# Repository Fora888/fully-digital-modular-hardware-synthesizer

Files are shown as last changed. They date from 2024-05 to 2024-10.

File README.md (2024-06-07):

# Fully digital modular synthesizer
A fully digital modular synthesizer specification

## Specification

### Audio data format
The audio data is transmitted and processed at 44.1kHz sample rate and 16 Bits of resolution

### Data transmission
Data transmission utilizes UART in combination with a simple protocol.
UART is configured at a baud rate of 2,000,000 with 8 data bits, 1 stop bit, no flow control and regular polarity. Signal levels are defined as 0V for low and 3.3V for high. However, all inputs and outputs should withstand voltages from +12V to -12V to prevent accidental damage when interfaced with analog equipment.
Due to UART's limitation of transmitting only 8 bits at a time and each audio sample requiring 16 bits, each sample is transmitted as three sequential packets. Each packet consists of 6 data bits followed by 2 order bits. Therefore a full UART frame looks like the following:
|1|6|2|1|
|-|-|-|-|
|Start bit|Data bits|Order bits|Stop bit|

The least significant 8 bits of a sample are sent first with order bits '00', followed by the middle 8 bits with order bits '10', and finally the most significant 4 bits with order bits '01'. The last two data bits of the last packet with order bits '01', as well as the order bit combination '11', remain unused for now but could be utilized for future extensions.

### Power
Modules are connected to +5V and ground via a 6 pin, 2 row, 2.54mm (0.1 inch) spacing header connector. These use the following pinout:

| | | |
| --- | --- | --- |
| 5v  | 5v  | GND |
| GND | GND | GND |

This asymmetric pattern ensures, that in case the header is plugged in incorrectly, the power supply is short-circuited  and the module doesn't get damaged. Therefore it is advisable for power supplys to feature some sort of fusing mechanism.
Since noisy power doesn't impact the sound quality of digital audio, switching power supplys are sufficient for voltage conversion

### Mechanical
Since UART necessitates only one cable for transmission, akin to mono audio, the mechanical specifications of virtually any existing analog modular synthesizer can be used. The examples are based on eurorack the eurorack specification with 128mm height and 3.5mm TS (mono) phone connectors.

## Comparison to analog

### Advantages
**Less noise** - Digital transmission ensures that the audio signal is received exactly as it was sent, without introducing noise during transmission. Furthermore many analog modules use analog-to-digital and digital-to-analog conversion, which introduce noise into the signal

**Reduced complexity** - Digital signals don't require clean power or buffering in order to deliver good audio. Merely two diodes and one or two resistors, which are always in the exact same configuration, are required per input or output. In addition all I/O is full 16 bit and the audio is inherently DC coupled.

**Lower Price** - Microprocessors are cheap and require relatively few and simple auxiliary components when compared to analog electronics. The reduced complexity of digital signal processing also leads to lower development costs.

### Disadvantages
**Latency** - Digital signal processing always comes with latency. In case of the examples, where audio is processed in blocks of 128 samples, this latency comes in at ~3 ms per module. Fast processors can however reduce the block size, reducing the latency to half of that or even less.

**Module selection** - The digital protocol described is still in its early stages of development and therefore there are no manufacturers for it yet. So the only way to use it is to build your own modules

## Implementations and examples
An implementation for the teensy audio library as well as several example modules can be found in the [Teensy](https://github.com/Fora888/fully-digital-modular-hardware-synthesizer/tree/main/Teensy) folder.

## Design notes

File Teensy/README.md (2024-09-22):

# Teensy audio library extension
## TeensyDigitalModularExtension
This folder is a arduino library, which contains an implementation of the protocol as input and output blocks for the teensy audio library, as well as arduino sketches and auxiliary blocks for several example modules listed below. The library can easily be imported with the zip file and the following guide: https://docs.arduino.cc/software/ide-v1/tutorials/installing-libraries/.

## PCB
This folder contains PCBs as well as panel designs for the example modules. All PCBs use 2.54mm spacing between components, which means you can also build these modules on perfboard and connect the components with wire, instead of ordering PCBs

### VCA
<p float="left">
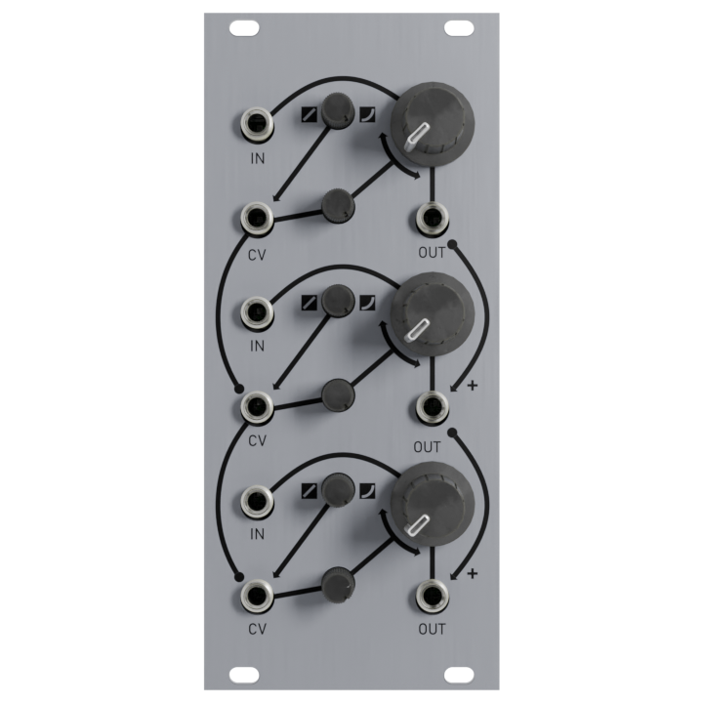
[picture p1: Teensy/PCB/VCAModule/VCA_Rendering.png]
  
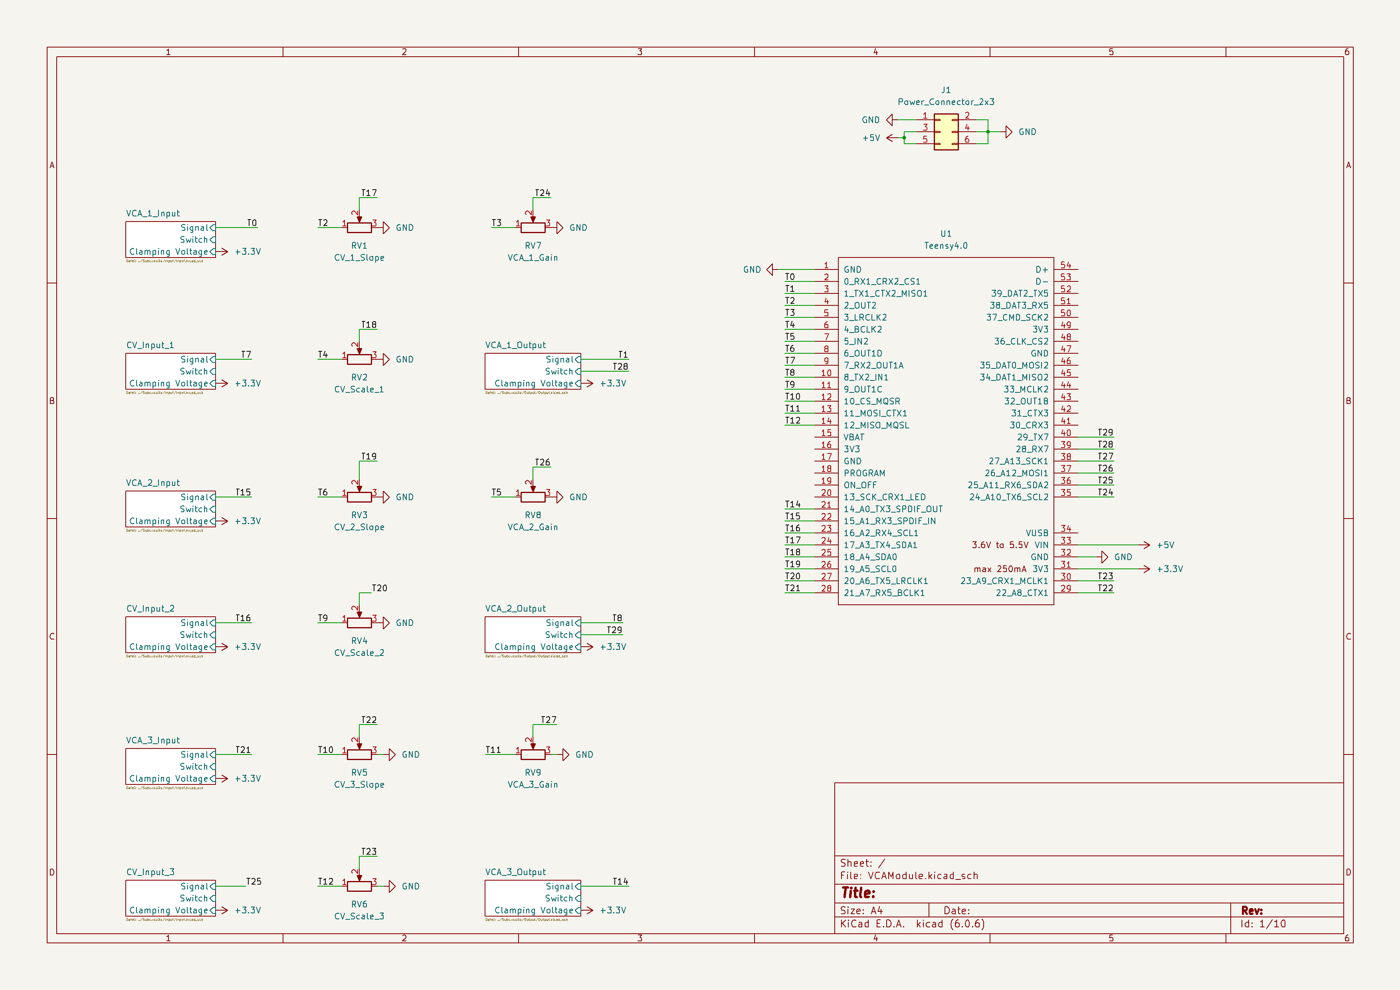
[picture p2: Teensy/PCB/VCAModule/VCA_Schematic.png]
  
</p>

### ADSR envelope generator
<p float="left">
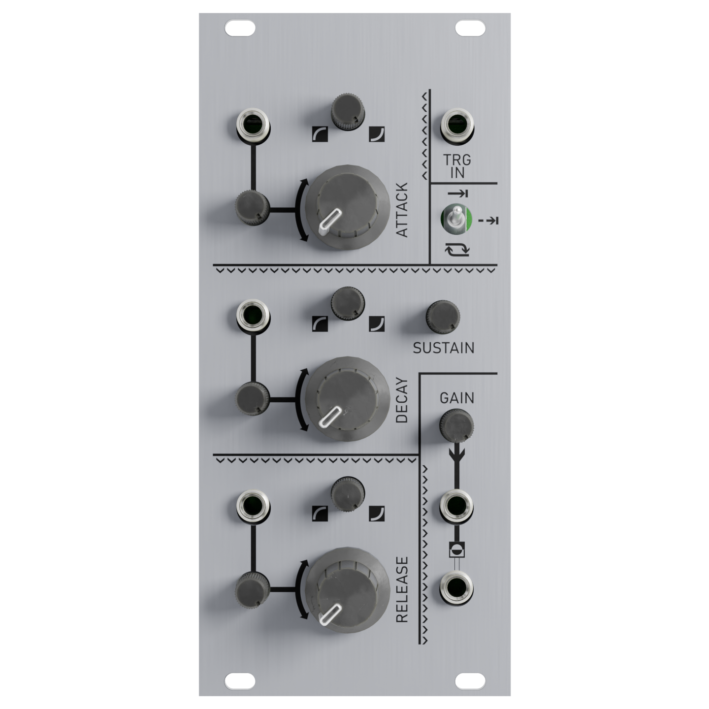
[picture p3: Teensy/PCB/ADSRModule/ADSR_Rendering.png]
  
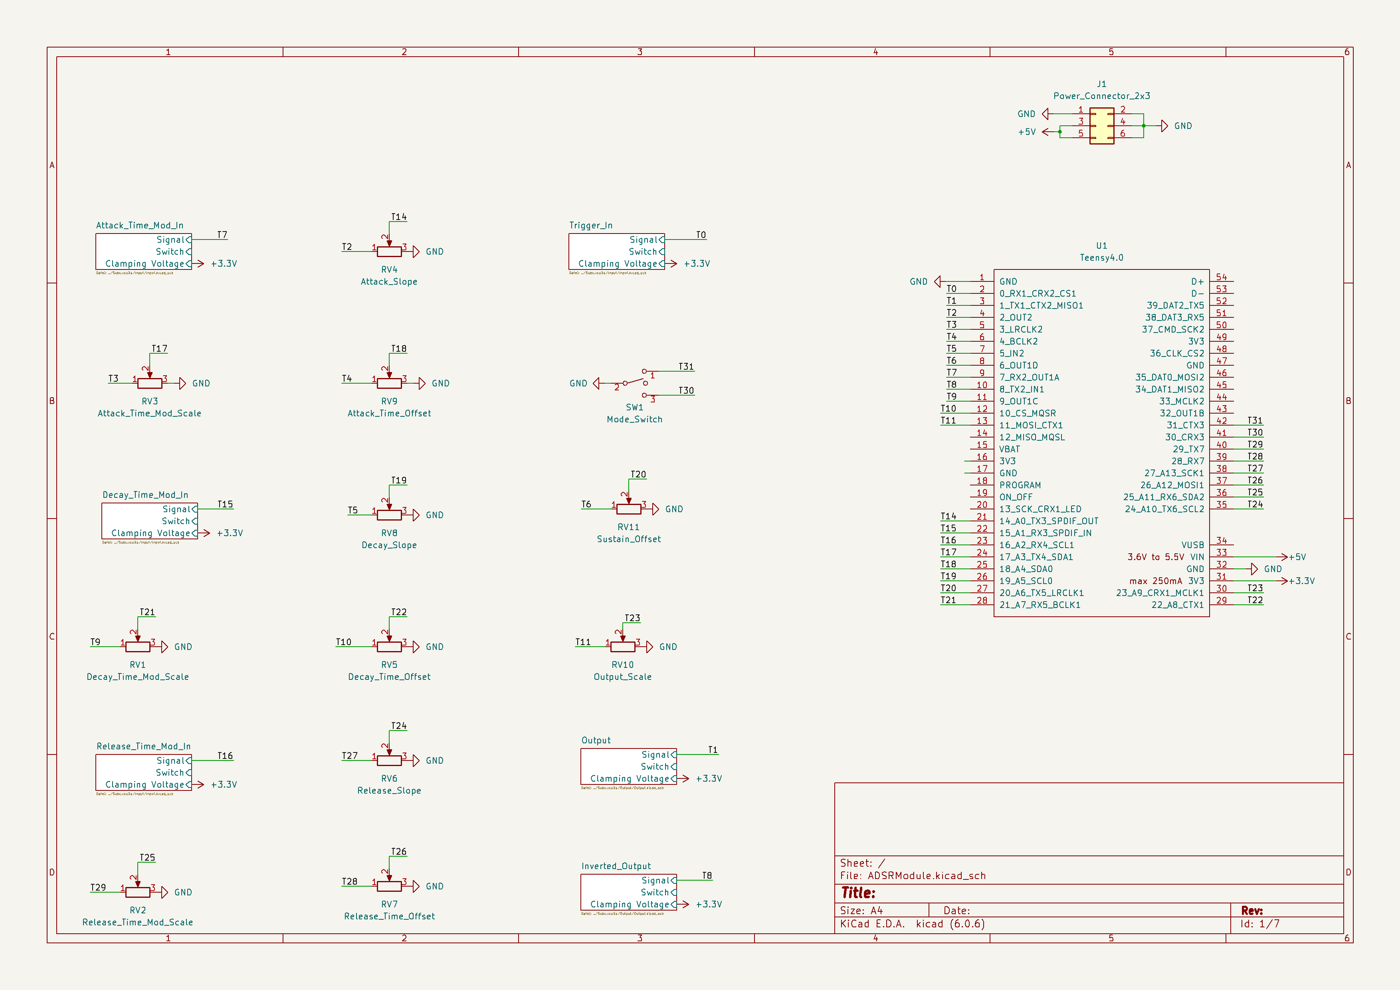
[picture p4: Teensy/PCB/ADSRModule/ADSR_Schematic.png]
  
</p>

### Wavetable oscillator
<p float="left">
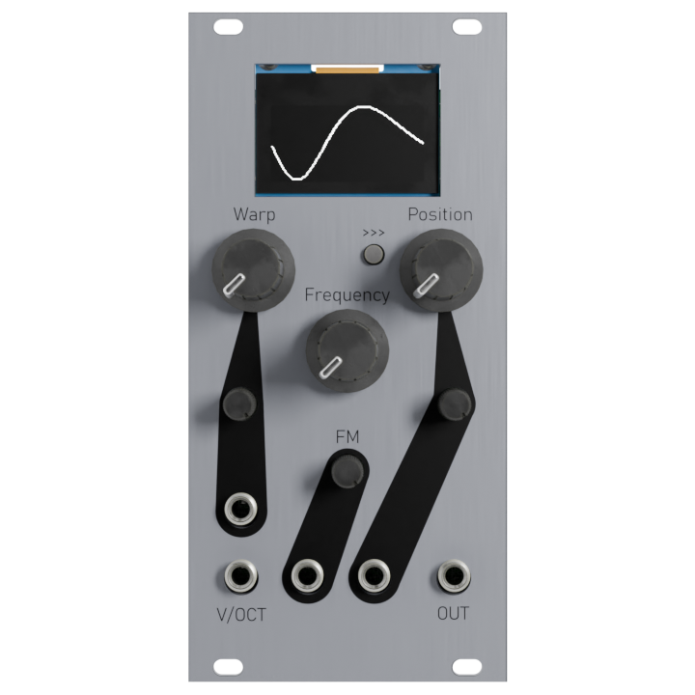
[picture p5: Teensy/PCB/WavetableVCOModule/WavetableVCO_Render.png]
  
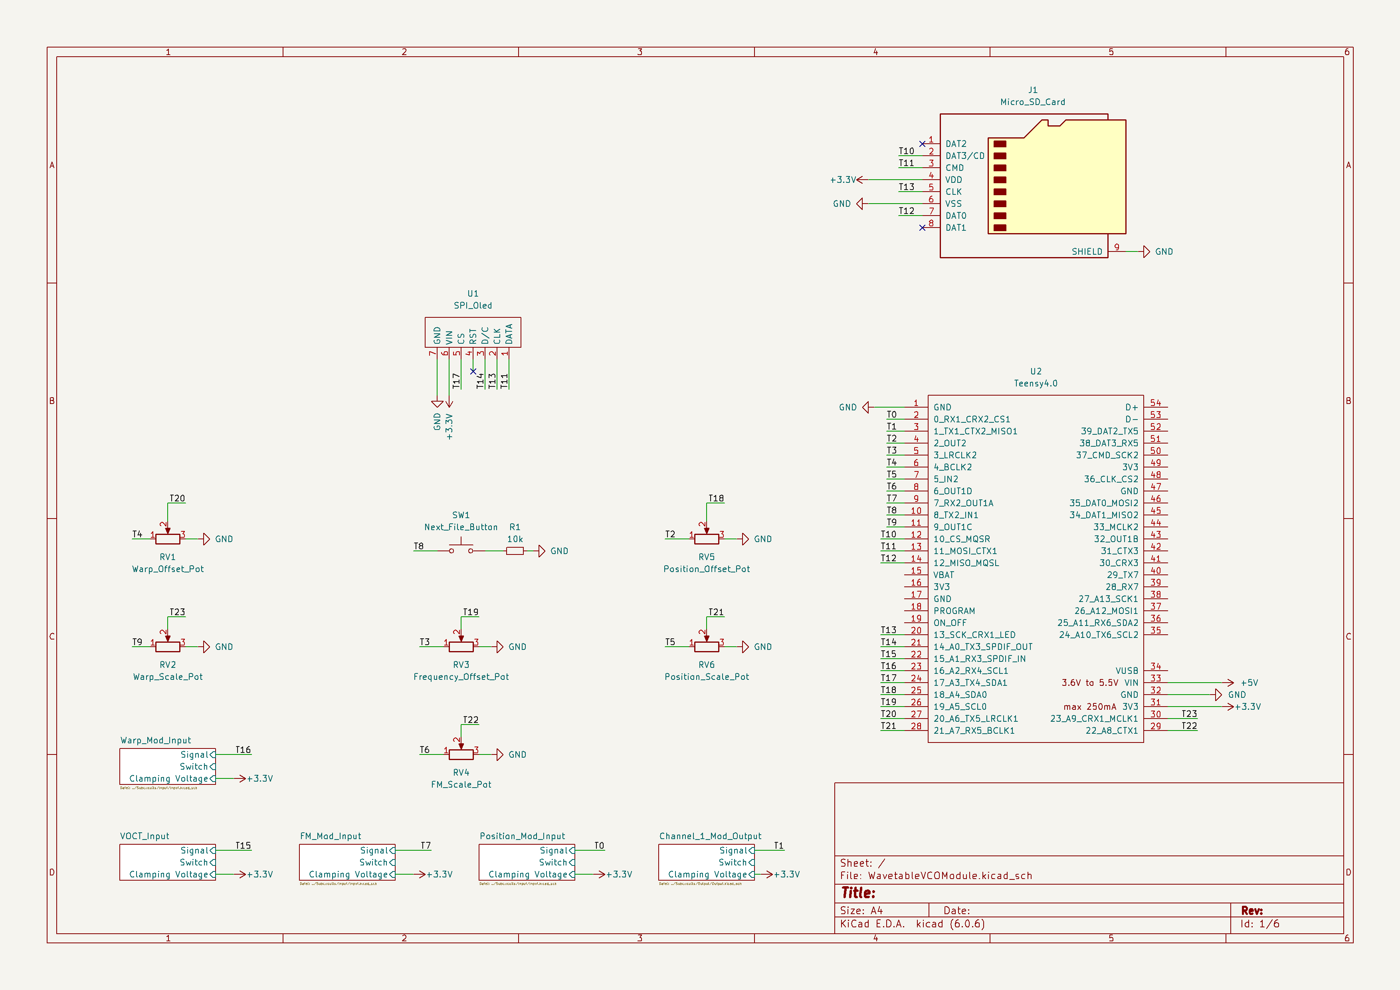
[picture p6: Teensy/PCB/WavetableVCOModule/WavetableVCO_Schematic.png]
  
</p>

### USB I/O
<p float="left">
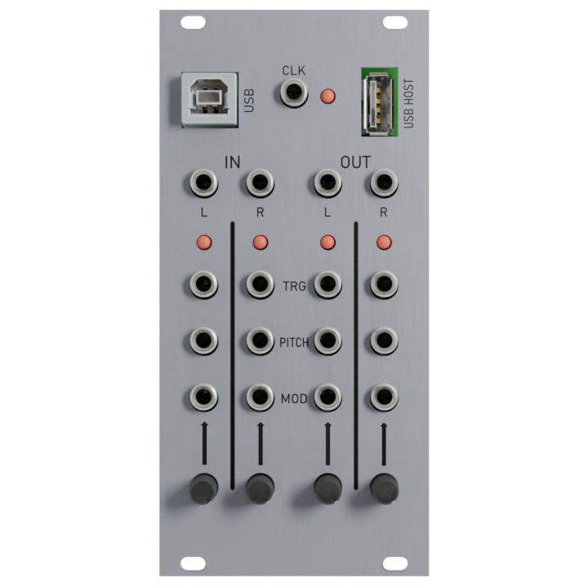
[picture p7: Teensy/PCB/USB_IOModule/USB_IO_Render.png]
  
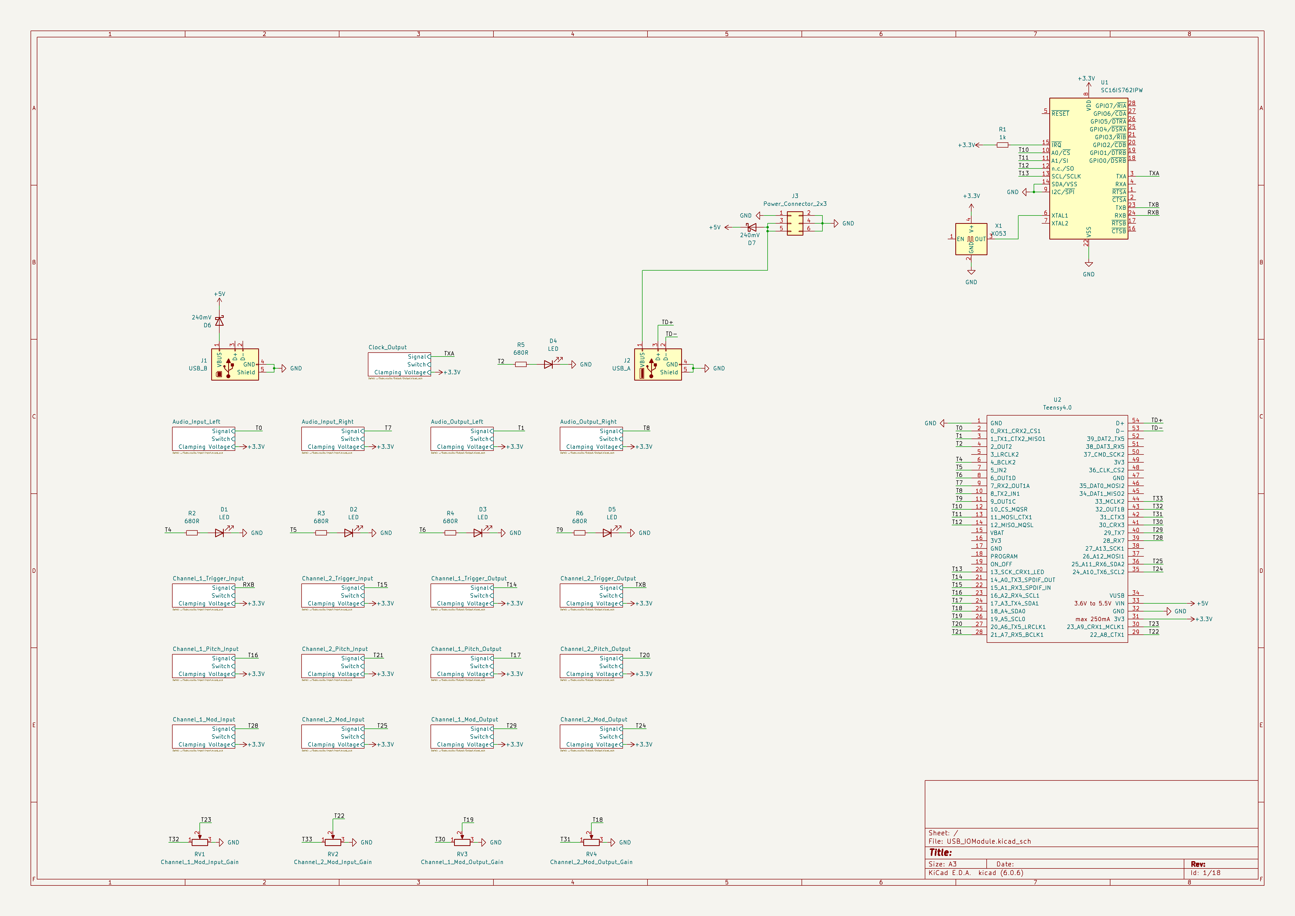
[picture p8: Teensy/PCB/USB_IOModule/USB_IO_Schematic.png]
  
</p>

### Analog I/O

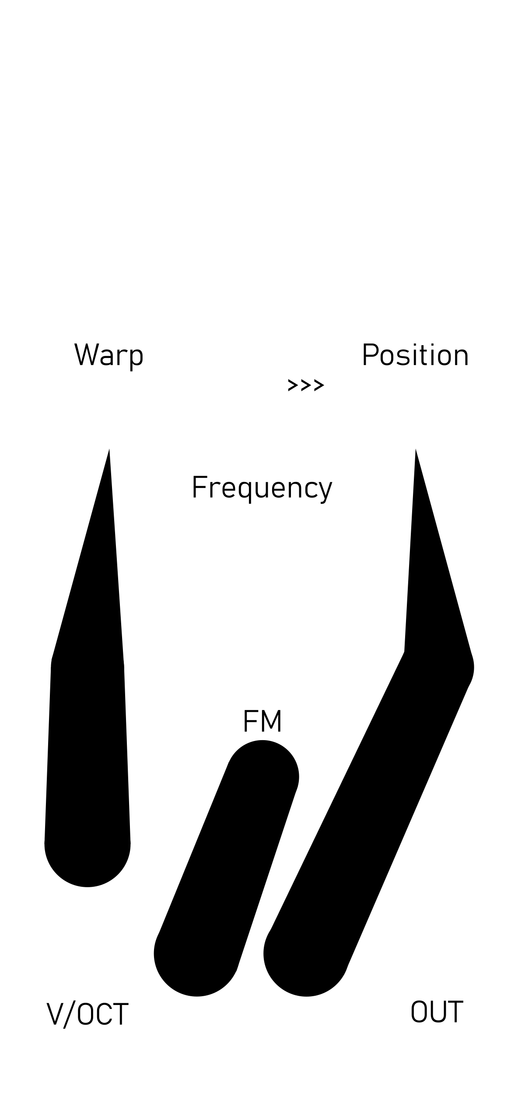
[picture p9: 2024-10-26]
Teensy/PCB/WavetableVCOModule/WavetableVCO_Artwork.png

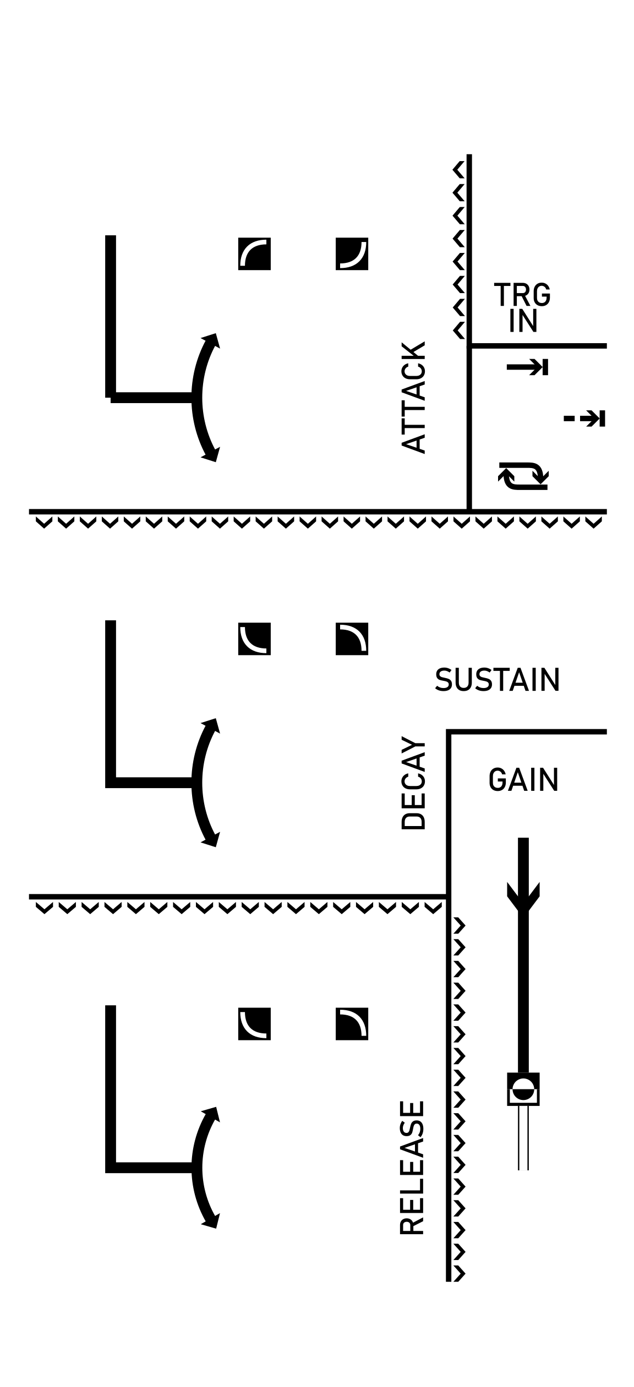
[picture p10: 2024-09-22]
Teensy/PCB/ADSRModule/ADSR_Artwork.png

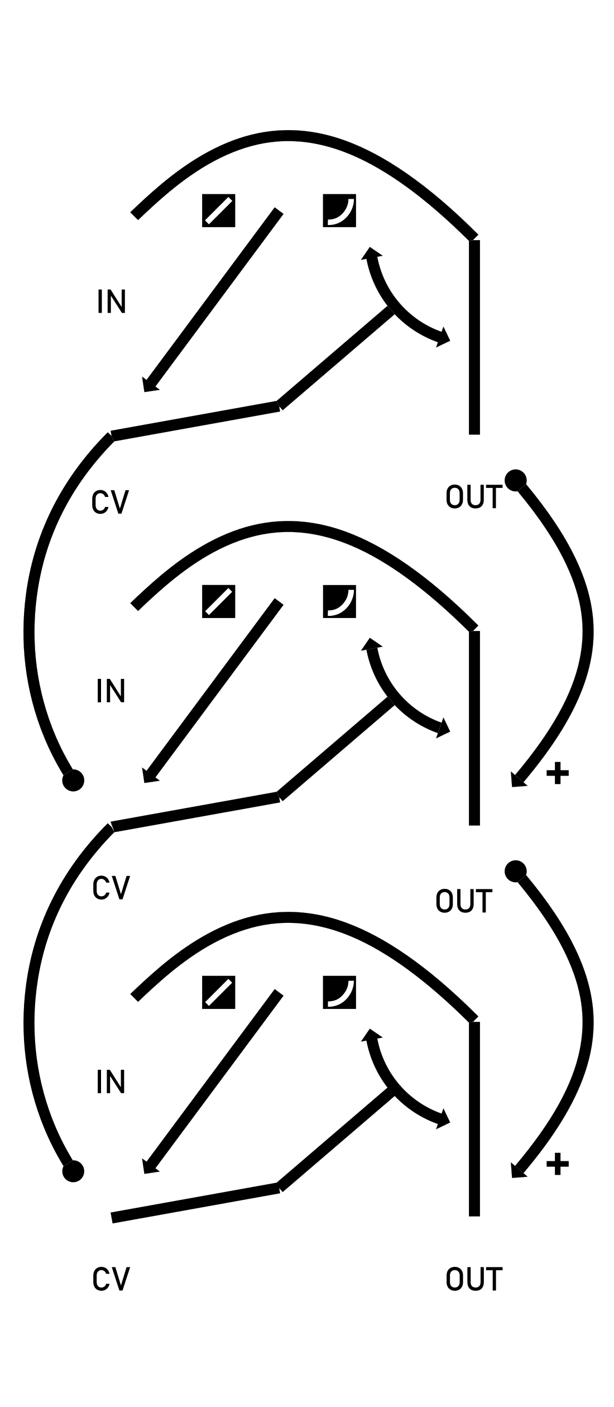
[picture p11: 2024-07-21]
Teensy/PCB/VCAModule/VCA_Artwork.png

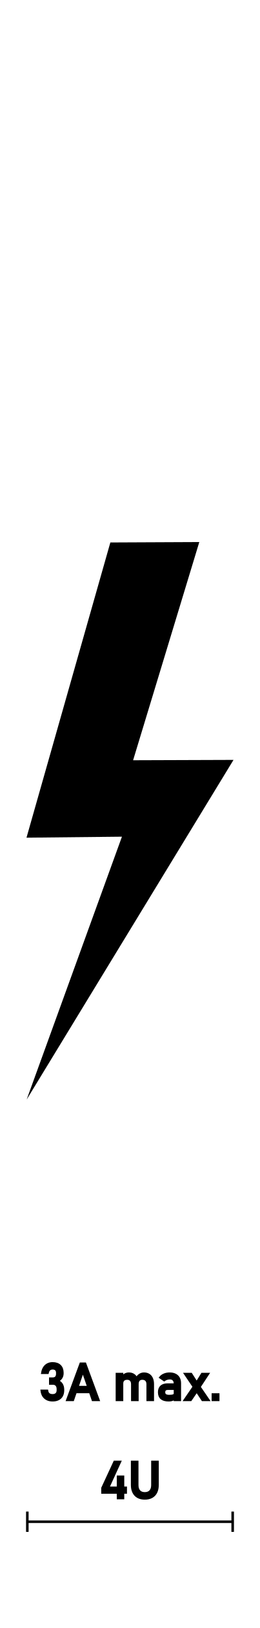
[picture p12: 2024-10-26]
Power Supply/USB-C_3A_PSU/USB-C_3A_PSU_Artwork.png

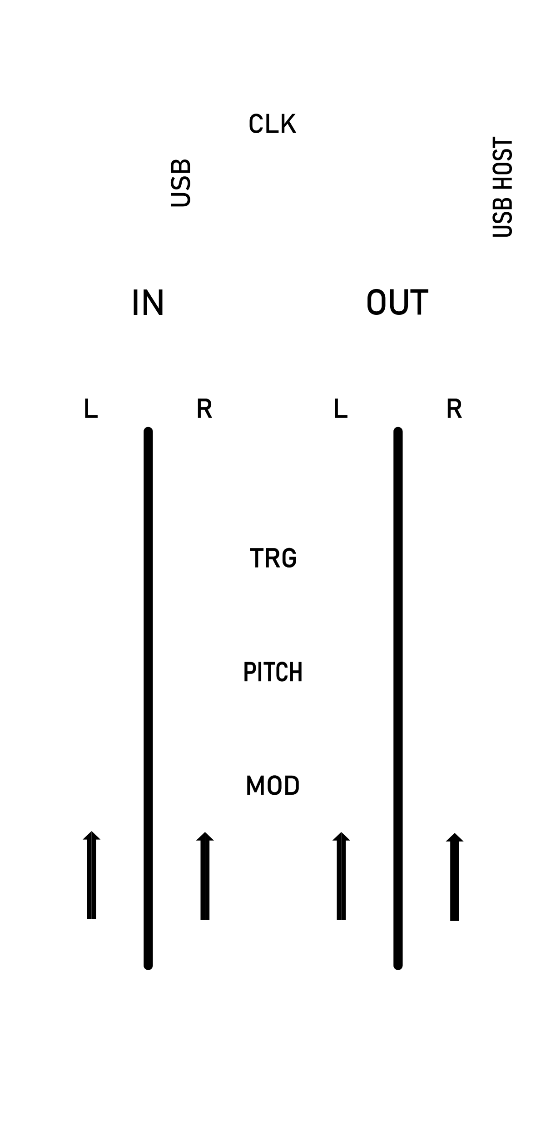
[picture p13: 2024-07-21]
Teensy/PCB/USB_IOModule/USB_IO_Artwork.png

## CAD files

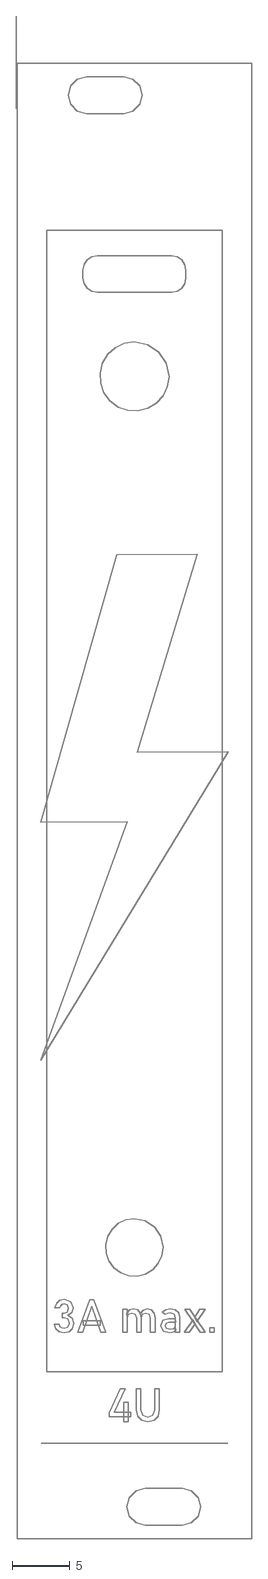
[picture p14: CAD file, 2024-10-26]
Power Supply/USB-C_3A_PSU/USB-C_3A_PSU_Cut.dxf
20.4 x 132.1

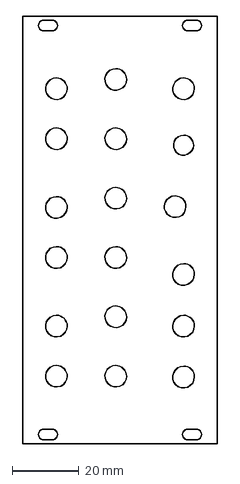
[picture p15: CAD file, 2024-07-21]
Teensy/PCB/ADSRModule/ADSR_Cut.dxf
58.4 x 128.0 mm

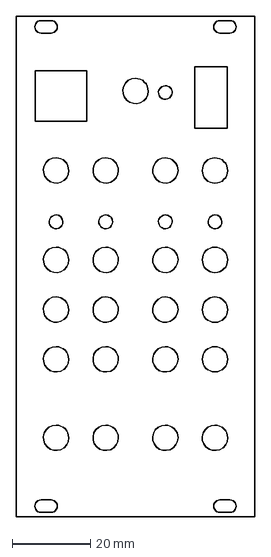
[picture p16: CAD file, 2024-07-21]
Teensy/PCB/USB_IOModule/USB_IO_Cut.dxf
61.0 x 128.0 mm

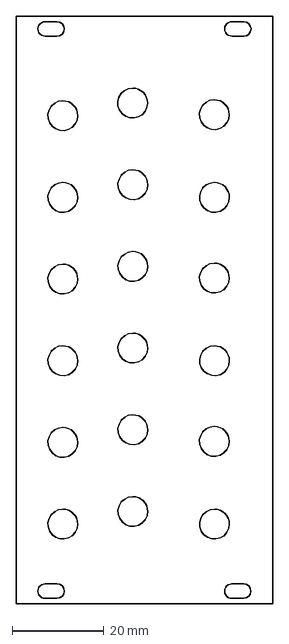
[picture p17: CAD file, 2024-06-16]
Teensy/PCB/VCAModule/VCA_Cut.dxf
55.8 x 127.9 mm

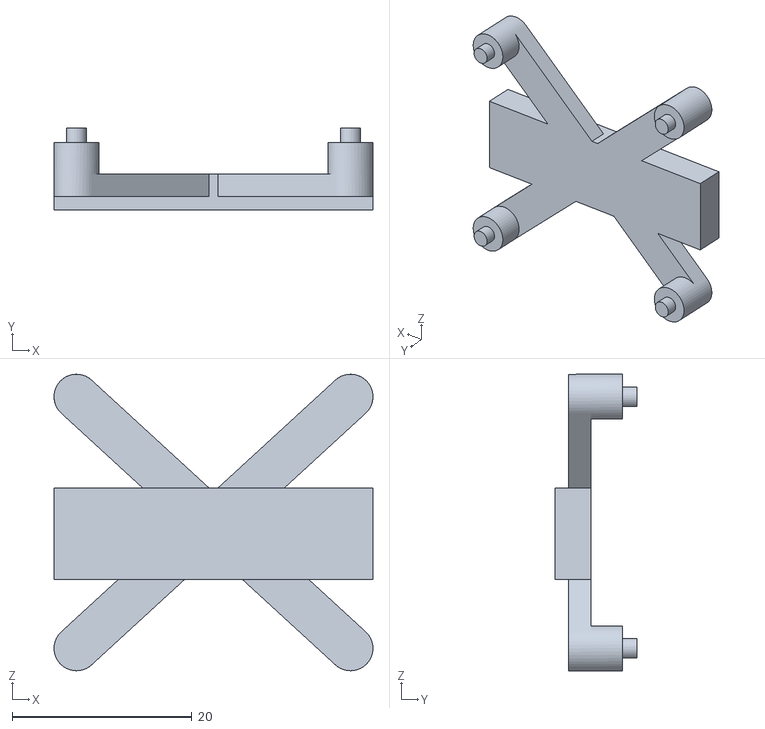
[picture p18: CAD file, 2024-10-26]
Teensy/PCB/WavetableVCOModule/WavetableVCO_OLEDBracket.stl
35.5 x 9.10 x 33.0

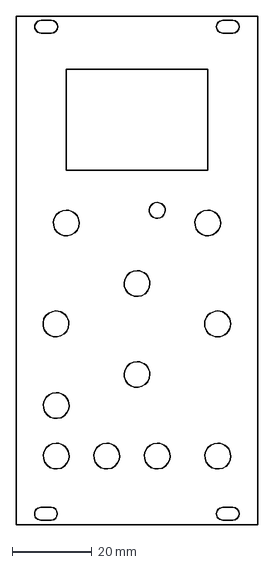
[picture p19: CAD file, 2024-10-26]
Teensy/PCB/WavetableVCOModule/WavetableVCO_Cut.dxf
60.8 x 127.9 mm

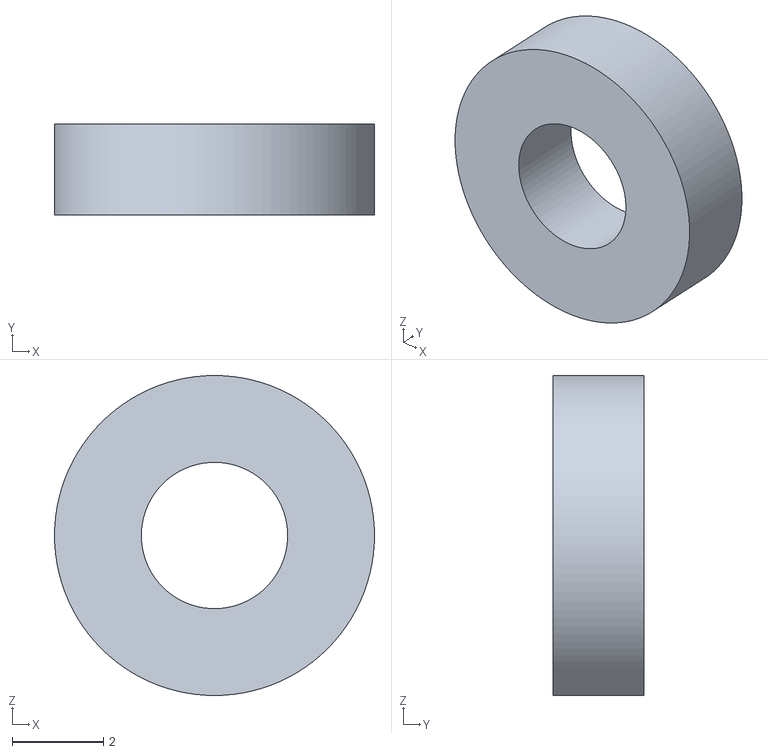
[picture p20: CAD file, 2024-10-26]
Teensy/PCB/WavetableVCOModule/WavetableVCO_ScrewSpacer.stl
7.00 x 2.00 x 7.00

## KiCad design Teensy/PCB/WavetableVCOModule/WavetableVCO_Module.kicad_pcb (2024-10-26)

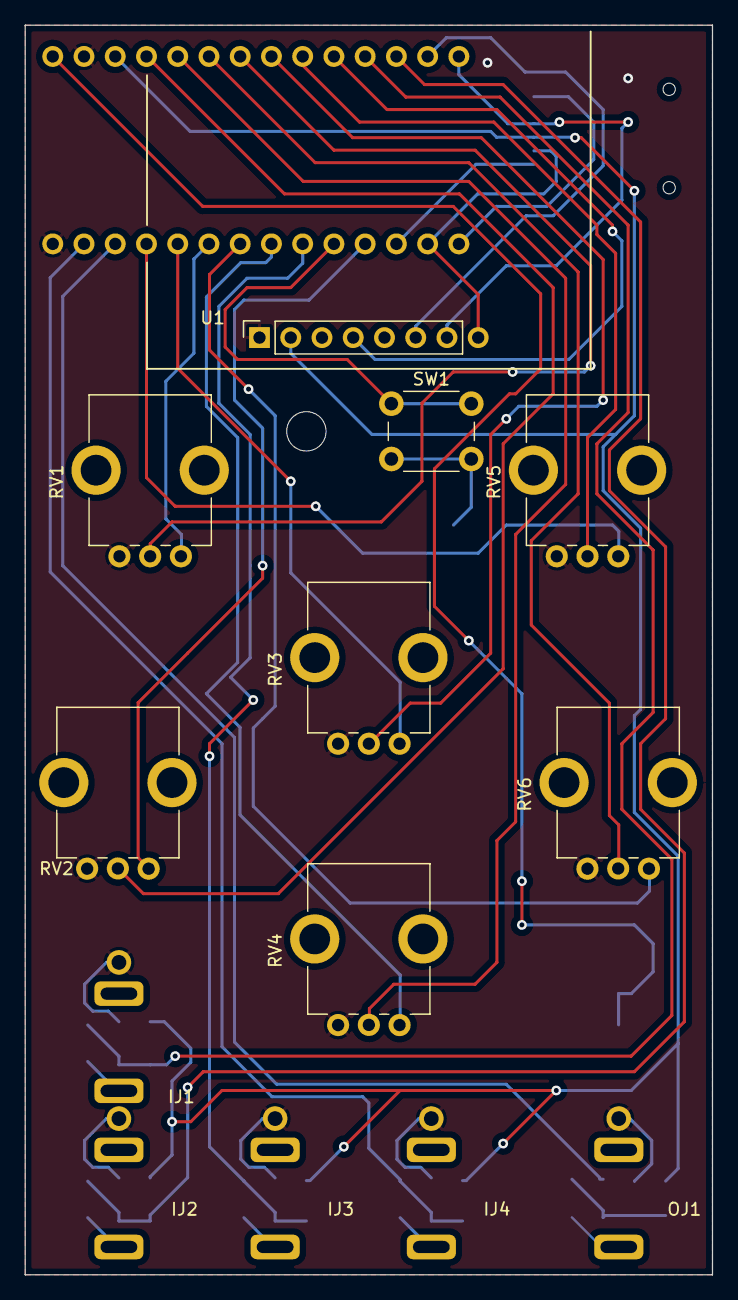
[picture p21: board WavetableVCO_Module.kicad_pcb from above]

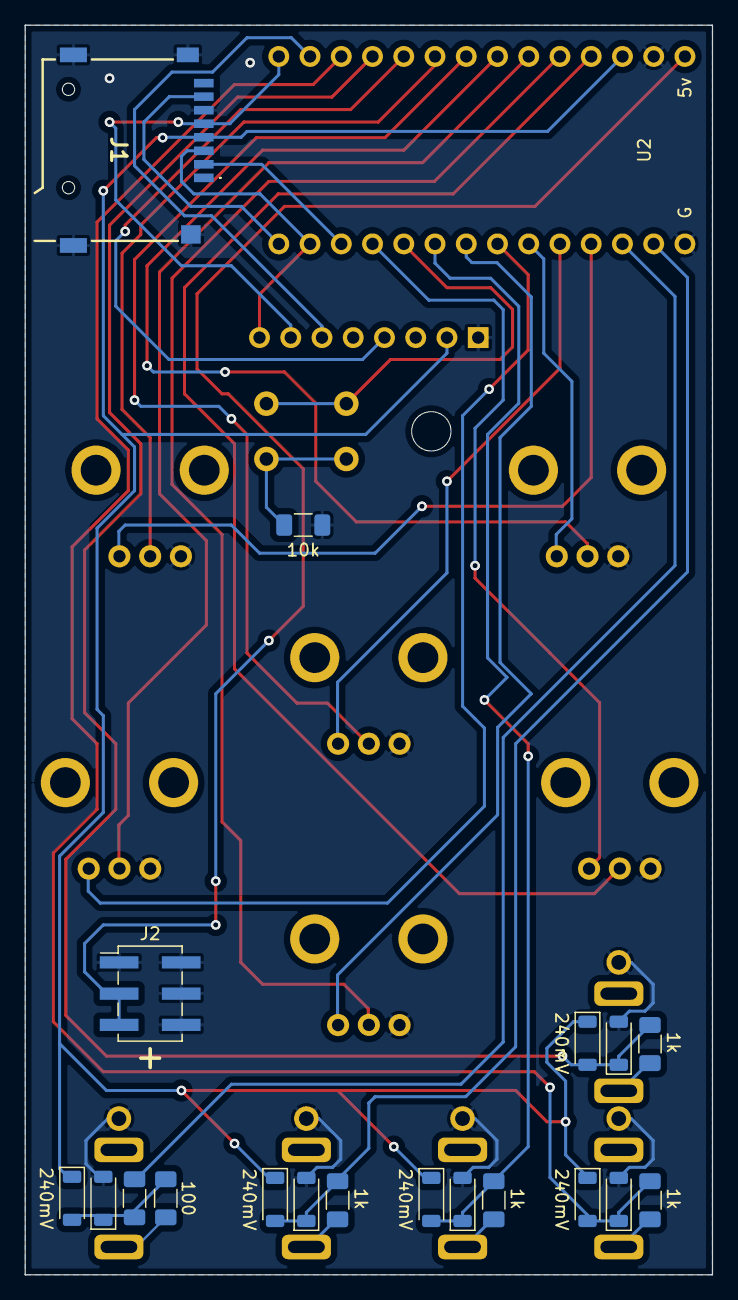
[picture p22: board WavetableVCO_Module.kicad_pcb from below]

Board: 2 copper layers, 55.9 x 101.6 mm, 33 parts (20 on the bottom side), 34 nets.

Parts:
ID1, ID2, ID3, ID4, ID5, ID6, ID7, ID8: 240mV; D_SOD-123 Handsolder
IJ1, IJ2, IJ3, IJ4: Input; 3.5mm Jack Perfboard
IR1, IR2, IR3, IR4: 1k; R_1206_3216Metric_Pad1.30x1.75mm_HandSolder
J1: Micro_SD_Card; MSD4A
J2: Power_Connector_2x3; PinHeader_2x03_P2.54mm_Vertical_SMD
OD1, OD2: 240mV; D_SOD-123 Handsolder
OJ1: Input; 3.5mm Jack Perfboard
OR1: 100; R_1206_3216Metric_Pad1.30x1.75mm_HandSolder
OR2: 900; R_1206_3216Metric_Pad1.30x1.75mm_HandSolder
R1: 10k; R_1206_3216Metric_Pad1.30x1.75mm_HandSolder
RV1: Warp_Offset_Pot; Bourns_PTV09A-4025FB103
RV2: Warp_Scale_Pot; Bourns_PTV09A-4020UB103
RV3: Frequency_Offset_Pot; Bourns_PTV09A-4025FB103
RV4: FM_Scale_Pot; Bourns_PTV09A-4020UB103
RV5: Position_Offset_Pot; Bourns_PTV09A-4025FB103
RV6: Position_Scale_Pot; Bourns_PTV09A-4020UB103
SW1: Next_File_Button; SW_PUSH_6mm_H13mm
U1: SPI_Oled; 1.5_inch_Oled
U2: Teensy4.0; Teensy 4.0 horizontal

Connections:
+3.3V: ID2.1 (K), ID4.1 (K), ID6.1 (K), ID8.1 (K), J1.4 (VDD), OD2.1 (K), U1.6 (VIN), U2.31 (3V3)
+5V: J2.3, J2.5, U2.33 (VIN)
/T0: ID7.1 (K), ID8.2 (A), IR4.2, U2.2 (0_RX1_CRX2_CS1)
/T1: OR2.2, U2.3 (1_TX1_CTX2_MISO1)
/T2: RV5.1, U2.4 (2_OUT2)
/T3: RV3.1, U2.5 (3_LRCLK2)
/T4: RV1.1, U2.6 (4_BCLK2)
/T5: RV6.1, U2.7 (5_IN2)
/T6: RV4.1, U2.8 (6_OUT1D)
/T7: ID5.1 (K), ID6.2 (A), IR3.2, U2.9 (7_RX2_OUT1A)
/T8: SW1.1, U2.10 (8_TX2_IN1)
/T9: RV2.1, U2.11 (9_OUT1C)
/T10: J1.2 (DAT3/CD), U2.12 (10_CS_MQSR)
/T11: J1.3 (CMD), U1.1 (DATA), U2.13 (11_MOSI_CTX1)
/T12: J1.7 (DAT0), U2.14 (12_MISO_MQSL)
/T13: J1.5 (CLK), U1.2 (CLK), U2.20 (13_SCK_CRX1_LED)
/T14: U1.3 (D/C), U2.21 (14_A0_TX3_SPDIF_OUT)
/T15: ID3.1 (K), ID4.2 (A), IR2.2, U2.22 (15_A1_RX3_SPDIF_IN)
/T16: ID1.1 (K), ID2.2 (A), IR1.2, U2.23 (16_A2_RX4_SCL1)
/T17: U1.5 (CS), U2.24 (17_A3_TX4_SDA1)
/T18: RV5.2, U2.25 (18_A4_SDA0)
/T19: RV3.2, U2.26 (19_A5_SCL0)
/T20: RV1.2, U2.27 (20_A6_TX5_LRCLK1)
/T21: RV6.2, U2.28 (21_A7_RX5_BCLK1)
/T22: RV4.2, U2.29 (22_A8_CTX1)
/T23: RV2.2, U2.30 (23_A9_CRX1_MCLK1)
GND: ID1.2 (A), ID3.2 (A), ID5.2 (A), ID7.2 (A), IJ1.G, IJ2.G, IJ3.G, IJ4.G, J1.6 (VSS), J1.9 (SHIELD), J2.1, J2.2, J2.4, J2.6, OD1.2 (A), OJ1.G, R1.1, RV1.3, RV2.3, RV3.3, RV4.3, RV5.3, RV6.3, U1.7 (GND), U2.1 (GND), U2.32 (GND)
unnamed: IJ1.T, IR1.1
unnamed: IJ2.T, IR2.1
unnamed: IJ3.T, IR3.1
unnamed: IJ4.T, IR4.1
unnamed: OD1.1 (K), OD2.2 (A), OR1.2, OR2.1
unnamed: OJ1.T, OR1.1
unnamed: R1.2, SW1.2

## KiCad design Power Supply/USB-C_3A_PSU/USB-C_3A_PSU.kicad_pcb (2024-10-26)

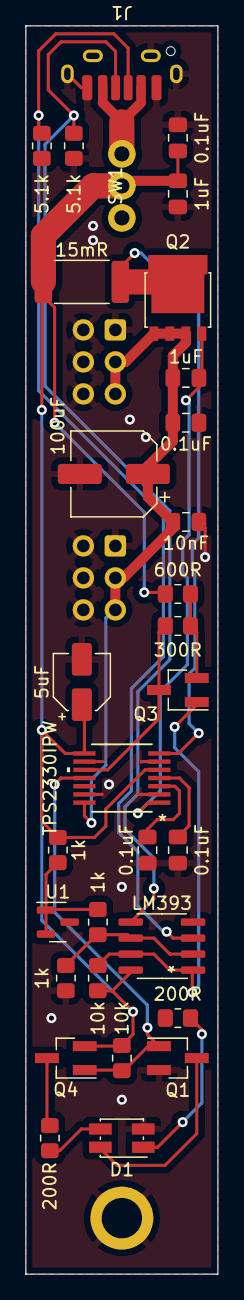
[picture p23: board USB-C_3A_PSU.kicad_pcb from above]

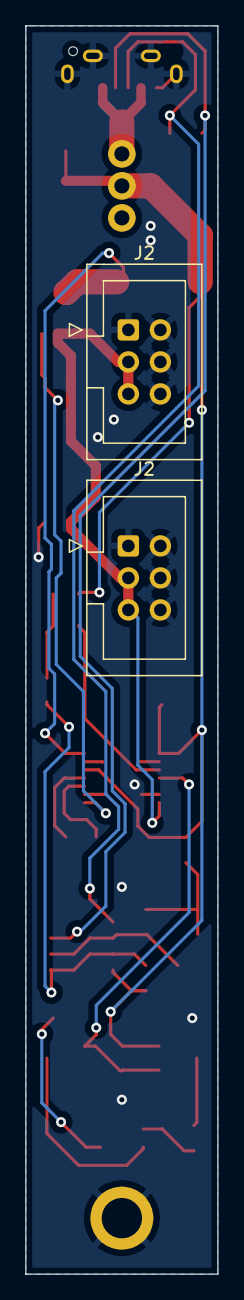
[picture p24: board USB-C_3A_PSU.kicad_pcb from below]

Board: 2 copper layers, 15.2 x 99.1 mm, 33 parts (2 on the bottom side), 20 nets.

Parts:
C1, C2, C4, C8: 0.1uF; C_0805_2012Metric_Pad1.18x1.45mm_HandSolder
C3, C5: 1uF; C_0805_2012Metric_Pad1.18x1.45mm_HandSolder
C6: 5uF; CP_Elec_4x5.4
C7: 10nF; C_0805_2012Metric_Pad1.18x1.45mm_HandSolder
C9: 100uF; CP_Elec_6.3x7.7
D1: LED_Dual_AKAK; LED_Kingbright_AAA3528ESGCT
J1: USB_C_Receptacle_USB2.0; USB_C_6Pin_Vert
J2, J2#2: Conn_02x03_Odd_Even; IDC-Header_2x03_P2.54mm_Vertical
Q1: Q_NMOS_GSD; SOT-23_Handsoldering
Q2: Q_NMOS_GSD; LFPAK56
Q3, Q4: Q_PMOS_GSD; SOT-23_Handsoldering
R1, R2: 5.1k; R_0805_2012Metric_Pad1.20x1.40mm_HandSolder
R3, R4, R5: 1k; R_0805_2012Metric_Pad1.20x1.40mm_HandSolder
R6, R12: 10k; R_0805_2012Metric_Pad1.20x1.40mm_HandSolder
R7: 15mR; R_2512_6332Metric_Pad1.40x3.35mm_HandSolder
R8: 600R; R_0805_2012Metric_Pad1.20x1.40mm_HandSolder
R9, R11: 200R; R_0805_2012Metric_Pad1.20x1.40mm_HandSolder
R10: 300R; R_0805_2012Metric_Pad1.20x1.40mm_HandSolder
SW1: SW_SPST; Miniature SPDT Toggle
U1: TL431DBZ; SOT-23
U2: LM393; SOIC-8_3.9x4.9mm_P1.27mm
U3: TPS2330IPW; PW14-M

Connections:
/1.25v Ref: R4.1, R5.1, U2.2 (-), U2.6 (_)
/5v In: C3.2, C4.2, C6.1, Q4.2 (S), R3.2, R6.1, R7.1, R8.1, R11.1, R12.2, SW1.2 (B), U2.8 (V+), U3.5 (VSENSE), U3.8 (IN)
/5v Out: C5.2, C7.1, C8.1, C9.1, J2.3, J2.5, J2#2.3, J2#2.5, Q2.2 (S), U3.14 (DISCH)
GND: C1.2, C2.2, C3.1, C4.1, C6.2, C7.2, C8.2, C9.2, D1.4 (K2), J1.A12 (GND), J1.B12 (GND), J1.S1 (SHIELD), J2.1, J2.2, J2.4, J2.6, J2#2.1, J2#2.2, J2#2.4, J2#2.6, Q1.2 (S), R1.2, R2.2, R5.2, U1.3 (A), U2.4 (V-), U3.2 (DGND), U3.6 (AGND), U3.9 (AGND), U3.13 (*ENABLE)
unnamed: C1.1, U3.3 (TIMER)
unnamed: C2.1, U3.4 (VREG)
unnamed: C5.1, Q2.1 (G), U3.1 (GATE)
unnamed: D1.1 (A1), R11.2
unnamed: D1.2 (K1), Q1.3 (D)
unnamed: D1.3 (A2), R9.2
unnamed: J1.A9 (VBUS), J1.B9 (VBUS), SW1.1 (A)
unnamed: J1.A5 (CC1), R2.1, U2.3 (+)
unnamed: J1.B5 (CC2), R1.1, U2.5 (+)
unnamed: Q1.1 (G), Q4.1 (G), R12.1, U3.11 (*FAULT)
unnamed: Q2.3 (D), R7.2, U3.7 (ISENSE)
unnamed: Q3.1 (G), R6.2, U2.1, U2.7
unnamed: Q3.2 (S), R8.2, R10.1
unnamed: Q3.3 (D), R10.2, U3.10 (ISET)
unnamed: Q4.3 (D), R9.1
unnamed: R3.1, R4.2, U1.1 (K), U1.2 (REF)

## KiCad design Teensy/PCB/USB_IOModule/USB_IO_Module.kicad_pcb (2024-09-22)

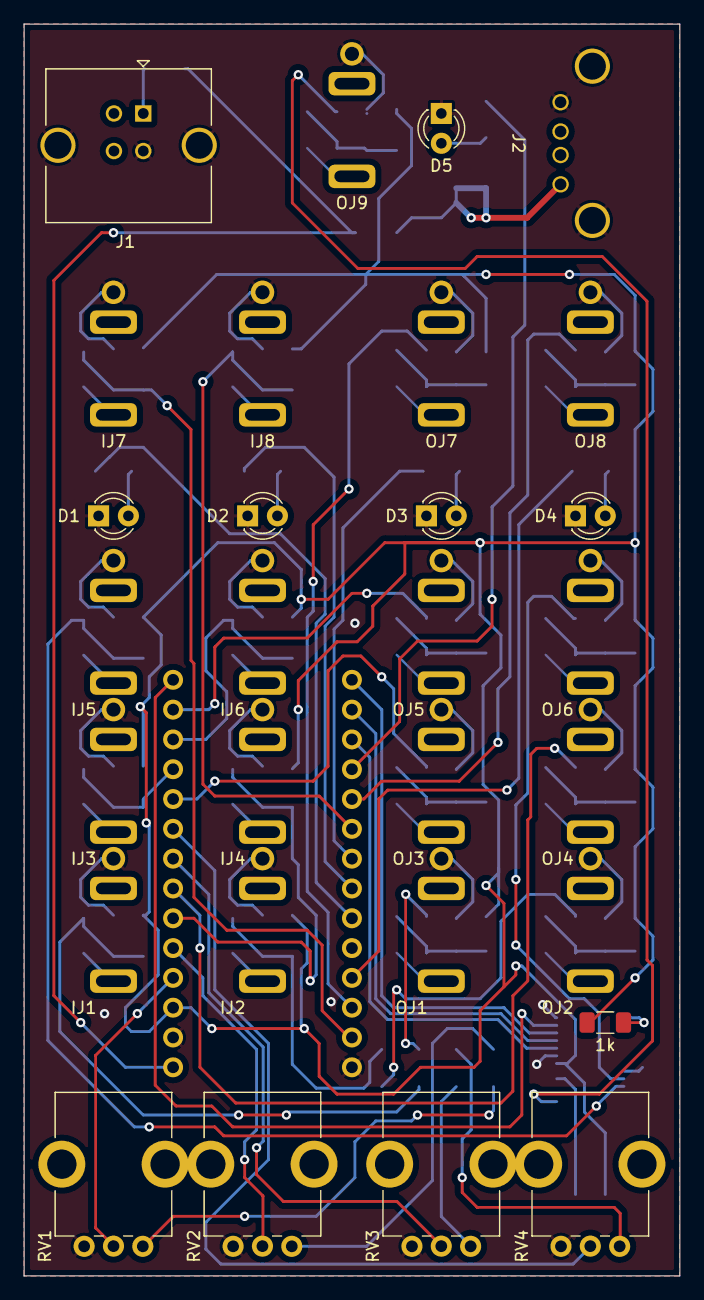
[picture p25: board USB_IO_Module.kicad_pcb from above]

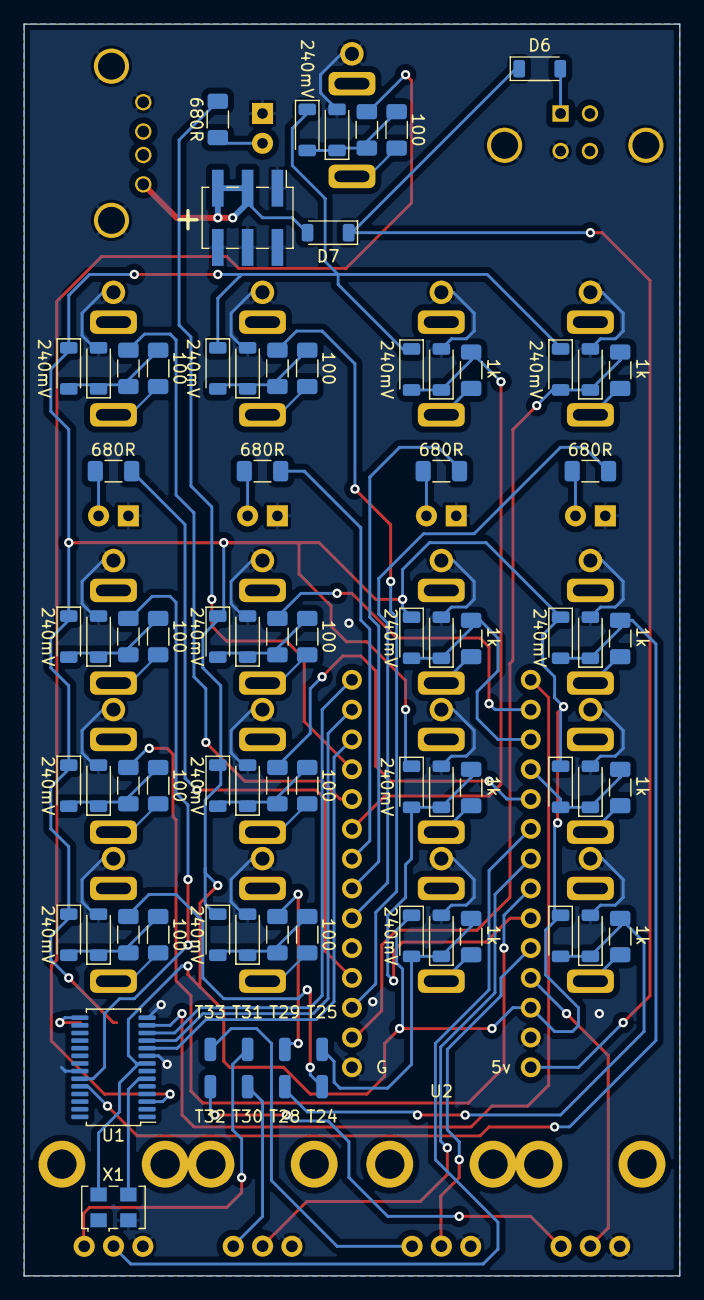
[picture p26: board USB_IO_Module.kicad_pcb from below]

Board: 2 copper layers, 55.9 x 106.7 mm, 101 parts (72 on the bottom side), 72 nets.

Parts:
D1, D2, D3, D4, D5: LED; LED_D3.0mm
D6, D7: 240mV; D_SOD-123 Handsolder
ID1, ID2, ID3, ID4, ID5, ID6, ID7, ID8, ID9, ID10, ID11, ID12, ID13, ID14, ID15, ID16: 240mV; D_SOD-123 Handsolder
IJ1, IJ2, IJ3, IJ4, IJ5, IJ6, IJ7, IJ8: Input; 3.5mm Jack Perfboard
IR1, IR2, IR3, IR4, IR5, IR6, IR7, IR8: 1k; R_1206_3216Metric_Pad1.30x1.75mm_HandSolder
J1: USB_B; USB_B_TE_5787834_Vertical
J2: USB_A; USB_A_Upright
J3: Power_Connector_2x3; PinHeader_2x03_P2.54mm_Vertical_SMD
OD1, OD2, OD3, OD4, OD5, OD6, OD7, OD8, OD9, OD10, OD11, OD12, OD13, OD14, OD15, OD16, OD17, OD18: 240mV; D_SOD-123 Handsolder
OJ1, OJ2, OJ3, OJ4, OJ5, OJ6, OJ7, OJ8, OJ9: Input; 3.5mm Jack Perfboard
OR1, OR3, OR5, OR7, OR9, OR11, OR13, OR15, OR17: 100; R_1206_3216Metric_Pad1.30x1.75mm_HandSolder
OR2, OR4, OR6, OR8, OR10, OR12, OR14, OR16, OR18: 900; R_1206_3216Metric_Pad1.30x1.75mm_HandSolder
R1: 1k; R_1206_3216Metric_Pad1.30x1.75mm_HandSolder
R2, R3, R4, R5, R6: 680R; R_1206_3216Metric_Pad1.30x1.75mm_HandSolder
RV1: Channel_1_Mod_Input_Gain; Bourns_PTV09A-4020UB103
RV2: Channel_2_Mod_Input_Gain; Bourns_PTV09A-4020UB103
RV3: Channel_1_Mod_Output_Gain; Bourns_PTV09A-4020UB103
RV4: Channel_2_Mod_Output_Gain; Bourns_PTV09A-4020UB103
U1: SC16IS762IPW; TSSOP-28_4.4x9.7mm_P0.65mm
U2: Teensy4.0; Teensy 4.0 horizontal
U2#2: Teensy4.0; Teensy 4.0 back pins
X1: XO53; Oscillator_SMD_EuroQuartz_XO53-4Pin_5.0x3.2mm

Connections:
+3.3V: ID2.1 (K), ID4.1 (K), ID6.1 (K), ID8.1 (K), ID10.1 (K), ID12.1 (K), ID14.1 (K), ID16.1 (K), OD2.1 (K), OD4.1 (K), OD6.1 (K), OD8.1 (K), OD10.1 (K), OD12.1 (K), OD14.1 (K), OD16.1 (K), OD18.1 (K), R1.1, U1.8 (VDD), U2.31 (3V3), X1.4 (V+)
+5V: D6.1 (K), D7.1 (K), U2.33 (VIN)
/RXB: ID9.1 (K), ID10.2 (A), IR5.2, U1.24 (RXB)
/T0: ID13.1 (K), ID14.2 (A), IR7.2, U2.2 (0_RX1_CRX2_CS1)
/T1: OR14.2, U2.3 (1_TX1_CTX2_MISO1)
/T2: R5.1, U2.4 (2_OUT2)
/T4: R2.1, U2.6 (4_BCLK2)
/T5: R3.1, U2.7 (5_IN2)
/T6: R4.1, U2.8 (6_OUT1D)
/T7: ID15.1 (K), ID16.2 (A), IR8.2, U2.9 (7_RX2_OUT1A)
/T8: OR16.2, U2.10 (8_TX2_IN1)
/T9: R6.1, U2.11 (9_OUT1C)
/T10: U1.10 (A0/~CS), U2.12 (10_CS_MQSR)
/T11: U1.11 (A1/SI), U2.13 (11_MOSI_CTX1)
/T12: U1.12 (n.c./SO), U2.14 (12_MISO_MQSL)
/T13: U1.13 (SCL/SCLK), U2.20 (13_SCK_CRX1_LED)
/T14: OR10.2, U2.21 (14_A0_TX3_SPDIF_OUT)
/T15: ID11.1 (K), ID12.2 (A), IR6.2, U2.22 (15_A1_RX3_SPDIF_IN)
/T16: ID5.1 (K), ID6.2 (A), IR3.2, U2.23 (16_A2_RX4_SCL1)
/T17: OR6.2, U2.24 (17_A3_TX4_SDA1)
/T18: RV4.2, U2.25 (18_A4_SDA0)
/T19: RV3.2, U2.26 (19_A5_SCL0)
/T20: OR8.2, U2.27 (20_A6_TX5_LRCLK1)
/T21: ID7.1 (K), ID8.2 (A), IR4.2, U2.28 (21_A7_RX5_BCLK1)
/T22: RV2.2, U2.29 (22_A8_CTX1)
/T23: RV1.2, U2.30 (23_A9_CRX1_MCLK1)
/T24: OR4.2, U2#2.35 (24_A10_TX6_SCL2)
/T25: ID3.1 (K), ID4.2 (A), IR2.2, U2#2.36 (25_A11_RX6_SDA2)
/T28: ID1.1 (K), ID2.2 (A), IR1.2, U2#2.39 (28_RX7)
/T29: OR2.2, U2#2.40 (29_TX7)
/T30: RV3.1, U2#2.41 (30_CRX3)
/T31: RV4.1, U2#2.42 (31_CTX3)
/T32: RV1.1, U2#2.43 (32_OUT1B)
/T33: RV2.1, U2#2.44 (33_MCLK2)
/TXA: OR18.2, U1.3 (TXA)
/TXB: OR12.2, U1.23 (TXB)
GND: D1.1 (K), D2.1 (K), D3.1 (K), D4.1 (K), D5.1 (K), ID1.2 (A), ID3.2 (A), ID5.2 (A), ID7.2 (A), ID9.2 (A), ID11.2 (A), ID13.2 (A), ID15.2 (A), IJ1.G, IJ2.G, IJ3.G, IJ4.G, IJ5.G, IJ6.G, IJ7.G, IJ8.G, J1.4 (GND), J1.5 (Shield), J2.4 (GND), J2.5 (Shield), J3.1, J3.2, J3.4, J3.6, OD1.2 (A), OD3.2 (A), OD5.2 (A), OD7.2 (A), OD9.2 (A), OD11.2 (A), OD13.2 (A), OD15.2 (A), OD17.2 (A), OJ1.G, OJ2.G, OJ3.G, OJ4.G, OJ5.G, OJ6.G, OJ7.G, OJ8.G, OJ9.G, RV1.3, RV2.3, RV3.3, RV4.3, U1.9 (I2C/~SPI), U1.14 (SDA/VSS), U1.22 (VSS), U2.1 (GND), U2.32 (GND), X1.2 (GND)
unnamed: D1.2 (A), R2.2
unnamed: D2.2 (A), R3.2
unnamed: D3.2 (A), R4.2
unnamed: D4.2 (A), R5.2
unnamed: D5.2 (A), R6.2
unnamed: D6.2 (A), J1.1 (VBUS)
unnamed: D7.2 (A), J2.1 (VBUS), J3.3, J3.5
unnamed: IJ1.T, IR1.1
unnamed: IJ2.T, IR2.1
unnamed: IJ3.T, IR3.1
unnamed: IJ4.T, IR4.1
unnamed: IJ5.T, IR5.1
unnamed: IJ6.T, IR6.1
unnamed: IJ7.T, IR7.1
unnamed: IJ8.T, IR8.1
unnamed: OD1.1 (K), OD2.2 (A), OR1.2, OR2.1
unnamed: OD3.1 (K), OD4.2 (A), OR3.2, OR4.1
unnamed: OD5.1 (K), OD6.2 (A), OR5.2, OR6.1
unnamed: OD7.1 (K), OD8.2 (A), OR7.2, OR8.1
unnamed: OD9.1 (K), OD10.2 (A), OR9.2, OR10.1
unnamed: OD11.1 (K), OD12.2 (A), OR11.2, OR12.1
unnamed: OD13.1 (K), OD14.2 (A), OR13.2, OR14.1
unnamed: OD15.1 (K), OD16.2 (A), OR15.2, OR16.1
unnamed: OD17.1 (K), OD18.2 (A), OR17.2, OR18.1
unnamed: OJ1.T, OR1.1
unnamed: OJ2.T, OR3.1
unnamed: OJ3.T, OR5.1
unnamed: OJ4.T, OR7.1
unnamed: OJ5.T, OR9.1
unnamed: OJ6.T, OR11.1
unnamed: OJ7.T, OR13.1
unnamed: OJ8.T, OR15.1
unnamed: OJ9.T, OR17.1
unnamed: R1.2, U1.15 (~IRQ)
unnamed: U1.6 (XTAL1), X1.3 (OUT)

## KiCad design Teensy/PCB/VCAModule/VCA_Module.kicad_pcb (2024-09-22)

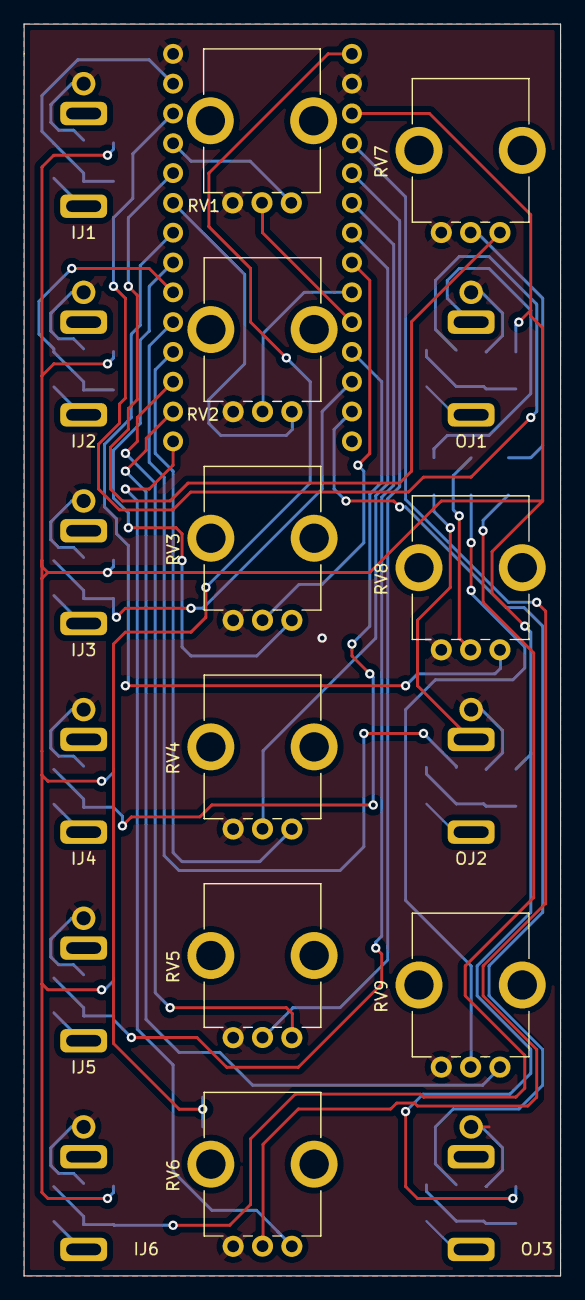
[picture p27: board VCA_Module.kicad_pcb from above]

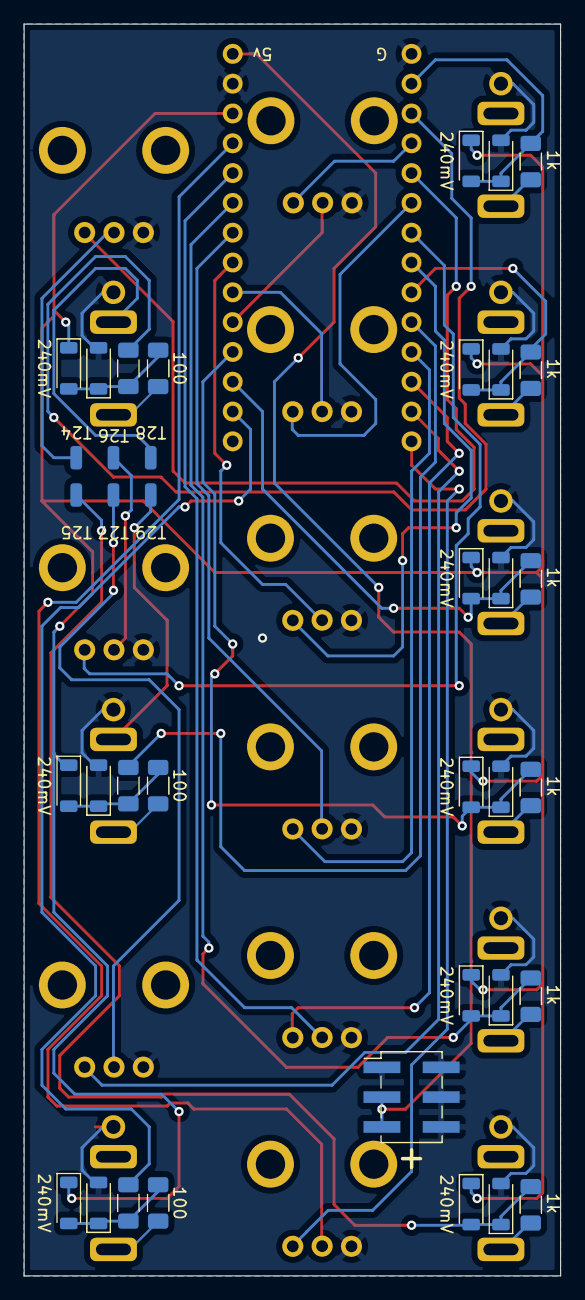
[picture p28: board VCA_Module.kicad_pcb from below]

Board: 2 copper layers, 45.7 x 106.7 mm, 51 parts (33 on the bottom side), 44 nets.

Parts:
ID1, ID2, ID3, ID4, ID5, ID6, ID7, ID8, ID9, ID10, ID11, ID12: 240mV; D_SOD-123 Handsolder
IJ1, IJ2, IJ3, IJ4, IJ5, IJ6: Input; 3.5mm Jack Perfboard
IR1, IR2, IR3, IR4, IR5, IR6: 1k; R_1206_3216Metric_Pad1.30x1.75mm_HandSolder
J1: Power_Connector_2x3; PinHeader_2x03_P2.54mm_Vertical_SMD
OD1, OD2, OD3, OD4, OD5, OD6: 240mV; D_SOD-123 Handsolder
OJ1, OJ2, OJ3: Input; 3.5mm Jack Perfboard
OR1, OR3, OR5: 100; R_1206_3216Metric_Pad1.30x1.75mm_HandSolder
OR2, OR4, OR6: 900; R_1206_3216Metric_Pad1.30x1.75mm_HandSolder
RV1: CV_1_Slope; Bourns_PTV09A-4020UB103
RV2: CV_Scale_1; Bourns_PTV09A-4020UB103
RV3: CV_2_Slope; Bourns_PTV09A-4020UB103
RV4: CV_Scale_2; Bourns_PTV09A-4020UB103
RV5: CV_3_Slope; Bourns_PTV09A-4020UB103
RV6: CV_Scale_3; Bourns_PTV09A-4020UB103
RV7: VCA_1_Gain; Bourns_PTV09A-4025FB103
RV8: VCA_2_Gain; Bourns_PTV09A-4025FB103
RV9: VCA_3_Gain; Bourns_PTV09A-4025FB103
U1: Teensy4.0; Teensy 4.0 horizontal
U1#2: Teensy4.0; Teensy 4.0 back pins

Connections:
+3.3V: ID2.1 (K), ID4.1 (K), ID6.1 (K), ID8.1 (K), ID10.1 (K), ID12.1 (K), OD2.1 (K), OD4.1 (K), OD6.1 (K), U1.31 (3V3)
+5V: J1.3, J1.5, U1.33 (VIN)
/T0: ID1.1 (K), ID2.2 (A), IR1.2, U1.2 (0_RX1_CRX2_CS1)
/T1: OR2.2, U1.3 (1_TX1_CTX2_MISO1)
/T2: RV1.1, U1.4 (2_OUT2)
/T3: RV7.1, U1.5 (3_LRCLK2)
/T4: RV2.1, U1.6 (4_BCLK2)
/T5: RV8.1, U1.7 (5_IN2)
/T6: RV3.1, U1.8 (6_OUT1D)
/T7: ID3.1 (K), ID4.2 (A), IR2.2, U1.9 (7_RX2_OUT1A)
/T8: OR4.2, U1.10 (8_TX2_IN1)
/T9: RV4.1, U1.11 (9_OUT1C)
/T10: RV5.1, U1.12 (10_CS_MQSR)
/T11: RV9.1, U1.13 (11_MOSI_CTX1)
/T12: RV6.1, U1.14 (12_MISO_MQSL)
/T14: OR6.2, U1.21 (14_A0_TX3_SPDIF_OUT)
/T15: ID5.1 (K), ID6.2 (A), IR3.2, U1.22 (15_A1_RX3_SPDIF_IN)
/T16: ID7.1 (K), ID8.2 (A), IR4.2, U1.23 (16_A2_RX4_SCL1)
/T17: RV1.2, U1.24 (17_A3_TX4_SDA1)
/T18: RV2.2, U1.25 (18_A4_SDA0)
/T19: RV3.2, U1.26 (19_A5_SCL0)
/T20: RV4.2, U1.27 (20_A6_TX5_LRCLK1)
/T21: ID9.1 (K), ID10.2 (A), IR5.2, U1.28 (21_A7_RX5_BCLK1)
/T22: RV5.2, U1.29 (22_A8_CTX1)
/T23: RV6.2, U1.30 (23_A9_CRX1_MCLK1)
/T24: RV7.2, U1#2.35 (24_A10_TX6_SCL2)
/T25: ID11.1 (K), ID12.2 (A), IR6.2, U1#2.36 (25_A11_RX6_SDA2)
/T26: RV8.2, U1#2.37 (26_A12_MOSI1)
/T27: RV9.2, U1#2.38 (27_A13_SCK1)
/T28: OJ1.S, U1#2.39 (28_RX7)
/T29: OJ2.S, U1#2.40 (29_TX7)
GND: ID1.2 (A), ID3.2 (A), ID5.2 (A), ID7.2 (A), ID9.2 (A), ID11.2 (A), IJ1.G, IJ2.G, IJ3.G, IJ4.G, IJ5.G, IJ6.G, J1.1, J1.2, J1.4, J1.6, OD1.2 (A), OD3.2 (A), OD5.2 (A), OJ1.G, OJ2.G, OJ3.G, RV1.3, RV2.3, RV3.3, RV4.3, RV5.3, RV6.3, RV7.3, RV8.3, RV9.3, U1.1 (GND), U1.32 (GND)
unnamed: IJ1.T, IR1.1
unnamed: IJ2.T, IR2.1
unnamed: IJ3.T, IR3.1
unnamed: IJ4.T, IR4.1
unnamed: IJ5.T, IR5.1
unnamed: IJ6.T, IR6.1
unnamed: OD1.1 (K), OD2.2 (A), OR1.2, OR2.1
unnamed: OD3.1 (K), OD4.2 (A), OR3.2, OR4.1
unnamed: OD5.1 (K), OD6.2 (A), OR5.2, OR6.1
unnamed: OJ1.T, OR1.1
unnamed: OJ2.T, OR3.1
unnamed: OJ3.T, OR5.1

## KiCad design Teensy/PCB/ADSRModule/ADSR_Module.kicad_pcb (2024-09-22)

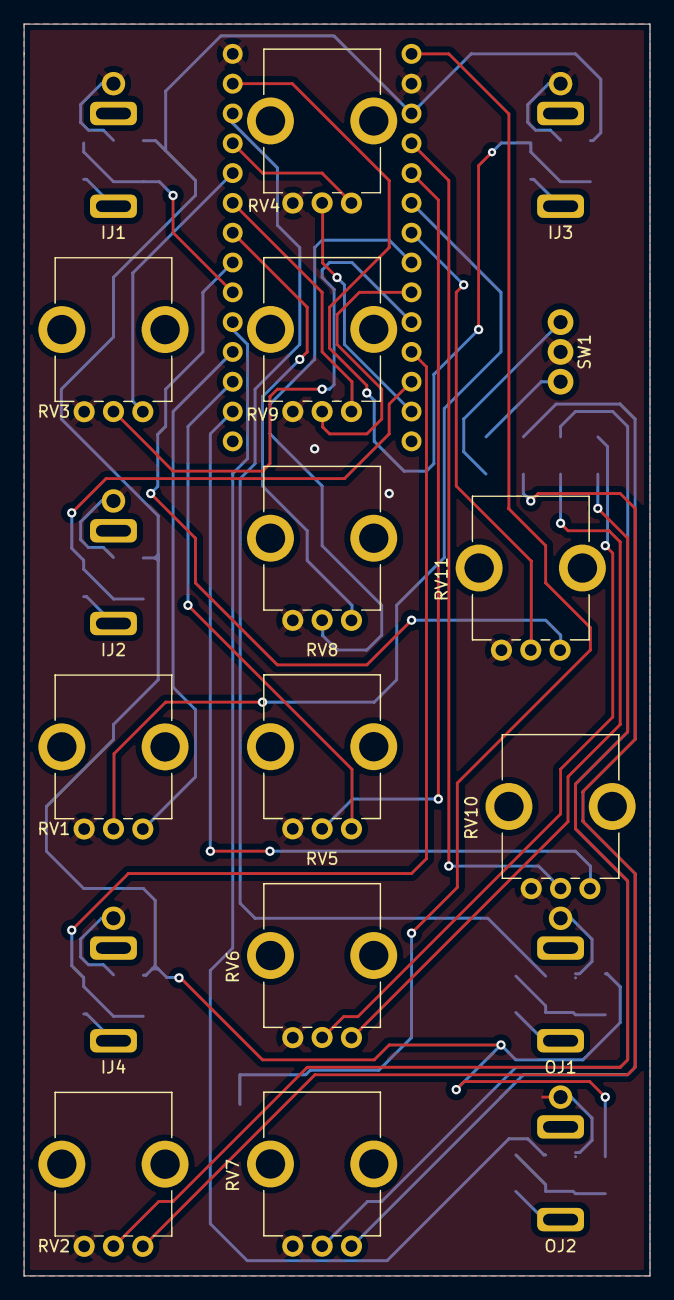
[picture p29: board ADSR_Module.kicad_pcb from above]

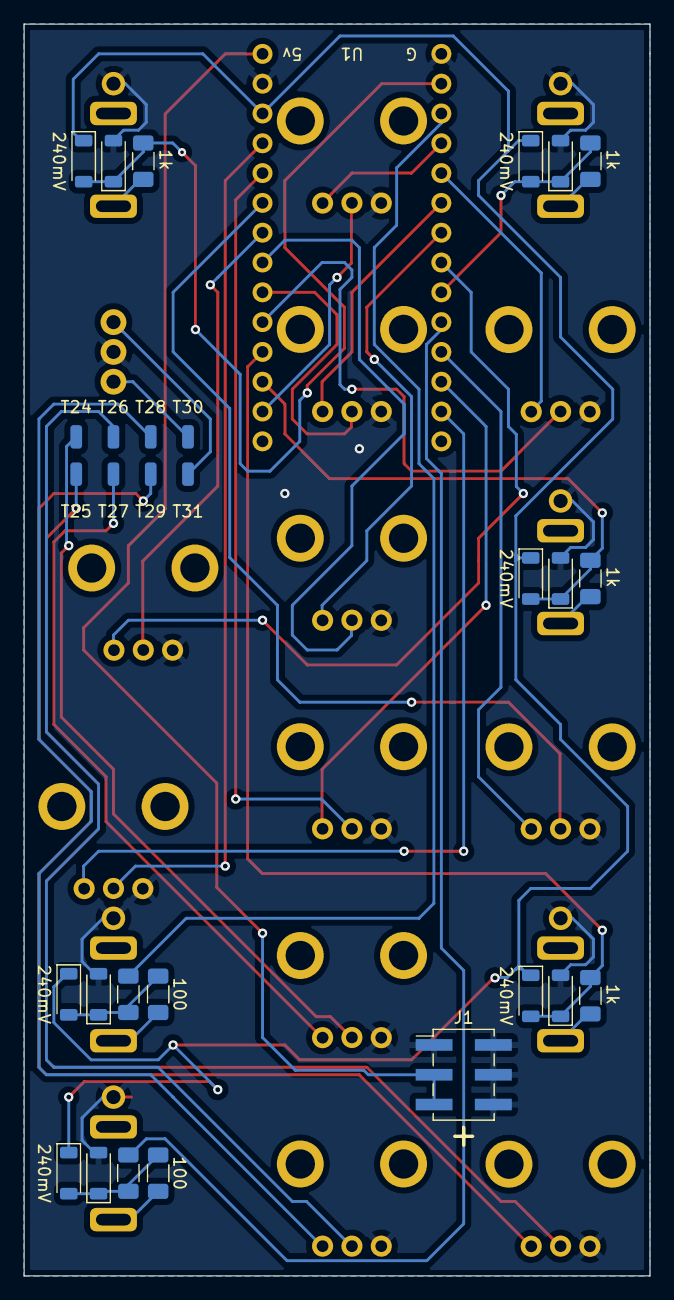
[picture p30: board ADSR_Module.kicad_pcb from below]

Board: 2 copper layers, 53.3 x 106.7 mm, 41 parts (23 on the bottom side), 41 nets.

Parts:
ID1, ID2, ID3, ID4, ID5, ID6, ID7, ID8: 240mV; D_SOD-123 Handsolder
IJ1, IJ2, IJ3, IJ4: Input; 3.5mm Jack Perfboard
IR1, IR2, IR3, IR4: 1k; R_1206_3216Metric_Pad1.30x1.75mm_HandSolder
J1: Power_Connector_2x3; PinHeader_2x03_P2.54mm_Vertical_SMD
OD1, OD2, OD3, OD4: 240mV; D_SOD-123 Handsolder
OJ1, OJ2: Input; 3.5mm Jack Perfboard
OR1, OR3: 100; R_1206_3216Metric_Pad1.30x1.75mm_HandSolder
OR2, OR4: 900; R_1206_3216Metric_Pad1.30x1.75mm_HandSolder
RV1: Decay_Time_Mod_Scale; Bourns_PTV09A-4020UB103
RV2: Release_Time_Mod_Scale; Bourns_PTV09A-4020UB103
RV3: Attack_Time_Mod_Scale; Bourns_PTV09A-4020UB103
RV4: Attack_Slope; Bourns_PTV09A-4020UB103
RV5: Decay_Time_Offset; Bourns_PTV09A-4025FB103
RV6: Release_Slope; Bourns_PTV09A-4020UB103
RV7: Release_Time_Offset; Bourns_PTV09A-4025FB103
RV8: Decay_Slope; Bourns_PTV09A-4020UB103
RV9: Attack_Time_Offset; Bourns_PTV09A-4025FB103
RV10: Output_Scale; Bourns_PTV09A-4020UB103
RV11: Sustain_Offset; Bourns_PTV09A-4020UB103
SW1: Mode_Switch; Miniature SPDT Toggle
U1: Teensy4.0; Teensy 4.0 horizontal
U1#2: Teensy4.0; Teensy 4.0 back pins

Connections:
+3.3V: ID2.1 (K), ID4.1 (K), ID6.1 (K), ID8.1 (K), OD2.1 (K), OD4.1 (K), U1.31 (3V3)
+5V: J1.3, J1.5, U1.33 (VIN)
/T0: ID5.1 (K), ID6.2 (A), IR3.2, U1.2 (0_RX1_CRX2_CS1)
/T1: OR2.2, U1.3 (1_TX1_CTX2_MISO1)
/T2: RV4.1, U1.4 (2_OUT2)
/T3: RV3.1, U1.5 (3_LRCLK2)
/T4: RV9.1, U1.6 (4_BCLK2)
/T5: RV8.1, U1.7 (5_IN2)
/T6: RV11.1, U1.8 (6_OUT1D)
/T7: ID1.1 (K), ID2.2 (A), IR1.2, U1.9 (7_RX2_OUT1A)
/T8: OR4.2, U1.10 (8_TX2_IN1)
/T9: RV1.1, U1.11 (9_OUT1C)
/T10: RV5.1, U1.12 (10_CS_MQSR)
/T11: RV10.1, U1.13 (11_MOSI_CTX1)
/T14: RV4.2, U1.21 (14_A0_TX3_SPDIF_OUT)
/T15: ID3.1 (K), ID4.2 (A), IR2.2, U1.22 (15_A1_RX3_SPDIF_IN)
/T16: ID7.1 (K), ID8.2 (A), IR4.2, U1.23 (16_A2_RX4_SCL1)
/T17: RV3.2, U1.24 (17_A3_TX4_SDA1)
/T18: RV9.2, U1.25 (18_A4_SDA0)
/T19: RV8.2, U1.26 (19_A5_SCL0)
/T20: RV11.2, U1.27 (20_A6_TX5_LRCLK1)
/T21: RV1.2, U1.28 (21_A7_RX5_BCLK1)
/T22: RV5.2, U1.29 (22_A8_CTX1)
/T23: RV10.2, U1.30 (23_A9_CRX1_MCLK1)
/T24: RV6.2, U1#2.35 (24_A10_TX6_SCL2)
/T25: RV2.2, U1#2.36 (25_A11_RX6_SDA2)
/T26: RV7.2, U1#2.37 (26_A12_MOSI1)
/T27: RV6.1, U1#2.38 (27_A13_SCK1)
/T28: RV7.1, U1#2.39 (28_RX7)
/T29: RV2.1, U1#2.40 (29_TX7)
/T30: SW1.3, U1#2.41 (30_CRX3)
/T31: SW1.1, U1#2.42 (31_CTX3)
GND: ID1.2 (A), ID3.2 (A), ID5.2 (A), ID7.2 (A), IJ1.G, IJ2.G, IJ3.G, IJ4.G, J1.1, J1.2, J1.4, J1.6, OD1.2 (A), OD3.2 (A), OJ1.G, OJ2.G, RV1.3, RV2.3, RV3.3, RV4.3, RV5.3, RV6.3, RV7.3, RV8.3, RV9.3, RV10.3, RV11.3, SW1.2, U1.1 (GND), U1.32 (GND)
unnamed: IJ1.T, IR1.1
unnamed: IJ2.T, IR2.1
unnamed: IJ3.T, IR3.1
unnamed: IJ4.T, IR4.1
unnamed: OD1.1 (K), OD2.2 (A), OR1.2, OR2.1
unnamed: OD3.1 (K), OD4.2 (A), OR3.2, OR4.1
unnamed: OJ1.T, OR1.1
unnamed: OJ2.T, OR3.1

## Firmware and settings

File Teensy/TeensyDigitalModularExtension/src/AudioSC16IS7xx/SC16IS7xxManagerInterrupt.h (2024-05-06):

#pragma once
#include "Arduino.h"
#include "SPI.h"
#include "AudioStream.h"

#define AUDIO_BAUD 2000000

class SC16IS7xxManager
{
	public:
		SC16IS7xxManager(uint16_t clockPin, uint16_t interruptPin, uint16_t CSPin)
		{
			SPI.begin();
			analogWriteFrequency(clockPin, 16 * AUDIO_BAUD);
			analogWrite(clockPin, 128);
			
			pinMode(CSPin, OUTPUT);
			digitalWrite(CSPin, HIGH);
			this->CSPin = CSPin;
			delayMicroseconds(1);
			
			SPI.beginTransaction(SPISettings(4000000, MSBFIRST, SPI_MODE0));

			setupChannel(0);
			setupChannel(1);

			manager = this;
			event.attachImmediate(&SPIinterruptRoutine);
			attachInterrupt(interruptPin, &interruptRoutine, FALLING);

		}

		void registerReceiveBuffer(uint8_t channel, int8_t* buffer)
		{
			if (channel == 0)
			{
				receiveBufferA->buffer = buffer;
				receiveBufferA->registered = true;
				receiveBufferA->position = 0;
			}
			else
			{
				receiveBufferB->buffer = buffer;
				receiveBufferB->registered = true;
				receiveBufferB->position = 0;
			}

			writeRegister(1, channel, 0b00000001 | readRegister(1, channel));
		}

		void registerSendBuffer(uint8_t channel, int8_t* buffer)
		{
			if (channel == 0)
			{
				sendBufferA->buffer = buffer;
				sendBufferA->registered = true;
				sendBufferA->position = 0;
			}
			else
			{
				sendBufferB->buffer = buffer;
				sendBufferB->registered = true;
				sendBufferB->position = 0;
			}

			writeRegister(1, channel, 0b00000010 | readRegister(1, channel));
		}

		uint16_t getBytesReceived(uint8_t channel)
		{
			return channel == 0 ? receiveBufferA->position : receiveBufferB->position;
		}

		bool getTransmitting()
		{
			return isTransmitting;
		}

		void getInterruptStatus()
		{
			while (isTransmitting) {};
			Serial.println(readRegister(2, 0), BIN);
			Serial.println(readRegister(1, 0), BIN);
			Serial.println();

		}

	private:		
		struct UARTBuffer 
		{
			int8_t* buffer;
			bool registered = false;
			uint16_t position = 0;
		};

		static SC16IS7xxManager* manager;
		bool isTransmitting = false;
		bool SPIlock = false;
		EventResponder event;
		uint8_t finishedTransmissionCount = 0;
		uint16_t CSPin = 0;
		uint16_t sentCharacters = 0;

		static void SPIinterruptRoutine(EventResponderRef event_responder)
		{
				Serial.println("SPI");
				manager->finishedTransmissionCount++;
				manager->ManageFIFO();
		}

		void ManageFIFO()
		{
			digitalWriteFast(CSPin, HIGH);
			delayNanoseconds(250);
			//Serial.println(readRegister(2, 0), BIN);
			SPI.beginTransaction(SPISettings(4000000, MSBFIRST, SPI_MODE0));
			if (finishedTransmissionCount == 0)
			{
				if (receiveBufferA->position >= AUDIO_BLOCK_SAMPLES * 3 - 1 || !receiveBufferA->registered)
				{
					//Serial.println("Skipping");
					finishedTransmissionCount++;
					sentCharacters = 0;
				}
				else
				{
					transferBuffer(receiveBufferA, 0, 0);
					return;
				}
			}

			if (finishedTransmissionCount == 1)
			{
				receiveBufferA->position += sentCharacters;
				if (receiveBufferB->position >= AUDIO_BLOCK_SAMPLES * 3 - 1 || !receiveBufferB->registered)
				{
					finishedTransmissionCount++;
					sentCharacters = 0;
				}
				else
				{
					transferBuffer(receiveBufferB, 1, 0);
					return;
				}
			}

			if (finishedTransmissionCount == 2)
			{
				receiveBufferB->position += sentCharacters;

				if (sendBufferA->position >= AUDIO_BLOCK_SAMPLES * 3 - 1 || !sendBufferA->registered)
				{
					finishedTransmissionCount++;
					sentCharacters = 0;
				}
				else
				{
					transferBuffer(sendBufferA, 0, 1);
					return;
				}
			}

			if (finishedTransmissionCount == 3)
			{
				sendBufferA->position += sentCharacters;

				if (sendBufferB->position >= AUDIO_BLOCK_SAMPLES * 3 - 1 || !sendBufferB->registered)
				{
					finishedTransmissionCount++;
					sentCharacters = 0;
				}
				else
				{
					transferBuffer(sendBufferB, 1, 1);
					return;
				}
			}

			if (finishedTransmissionCount == 4)
			{
				sendBufferB->position += sentCharacters;

				finishedTransmissionCount = 0;	
				isTransmitting = false;
				Serial.println(readRegister(2, 0),BIN);
			}
		}

		void transferBuffer(UARTBuffer* buffer, uint8_t channel, bool send)
		{
			uint16_t bufferSpaces = ((AUDIO_BLOCK_SAMPLES * 3) - buffer->position) - 1;
			uint8_t registerValue = readRegister(send ? 8 : 9, channel);
			if (registerValue >= bufferSpaces)
			{
				writeRegister(1, channel, (send ? 0b00000001 : 0b00000010) & readRegister(1, channel)); //DisableInterrupt
				Serial.println("Disabling");
			}

			sentCharacters = min(registerValue, bufferSpaces);
			digitalWriteFast(CSPin, LOW);
			delayNanoseconds(500);
			if (send)
			{
				SPI.transfer(0b00000000 | ((channel & 0b00000001) << 1));
				SPI.transfer(&buffer->buffer[buffer->position], NULL, sentCharacters, event);
			}
			else
			{
				SPI.transfer(0b10000000 | ((channel & 0b00000001) << 1));
				SPI.transfer(NULL, &buffer->buffer[buffer->position], sentCharacters, event);
			}
		}

		static void interruptRoutine()
		{
			Serial.println("PIN");
			if (manager->isTransmitting == false)
			{
				manager->isTransmitting = true;
				manager->ManageFIFO();
			}
		}

		void setupChannel(byte channel)
		{
			//Disable all interrupts
			writeRegister(1, channel, 0b00000000);

			//Eneable enhanced Functions for TX empty interrupt
			writeRegister(3, channel, 0xBF);
			writeRegister(2, channel, 0b00010000);
			
			//Set clock divisor to 1
			writeRegister(3, channel, 0b10000011);
			writeRegister(0, channel, 1);
			writeRegister(1, channel, 0);
			writeRegister(3, channel, 0b00000011);

			//Eneable FIFO
			writeRegister(2, channel, 0b00000001);

			//Eneable Trigger Level Register
			writeRegister(4, channel, 0b00000100);

			//Eneable TLR Register
			writeRegister(4, channel, 0b00000100);

			//Set FIFO level to 48
			writeRegister(7, channel, 0b11001100);
		}
		
		void writeRegister(uint8_t registerAddress, bool channel, byte value)
		{
			noInterrupts();
			digitalWriteFast(CSPin, LOW);
			delayNanoseconds(500);

			uint8_t sendBuffer[2];
			sendBuffer[0] = 0 | ((registerAddress & 0b00001111) << 3) | ((channel & 0b00000001) << 1);
			sendBuffer[1] = value;
			SPI.transfer(sendBuffer, nullptr, 2);

			digitalWriteFast(CSPin, HIGH);
			delayNanoseconds(500);
			interrupts();
		}

		uint8_t readRegister(uint8_t registerAddress, bool channel)
		{
			noInterrupts();
			digitalWriteFast(CSPin, LOW);
			delayNanoseconds(500);

			uint8_t returnBuffer[2];
			uint8_t sendBuffer[2];
			sendBuffer[0] = (0b10000000 | ((registerAddress & 0b00001111) << 3) | ((channel & 0b00000001) << 1));
			sendBuffer[1] = 0;
			SPI.transfer(sendBuffer, returnBuffer, 2);

			digitalWriteFast(CSPin, HIGH);
			delayNanoseconds(500);
			interrupts();
			return returnBuffer[1];
		}



		UARTBuffer* receiveBufferA = new UARTBuffer();
		UARTBuffer* receiveBufferB = new UARTBuffer();
		UARTBuffer* sendBufferA = new UARTBuffer();
		UARTBuffer* sendBufferB = new UARTBuffer();



};

SC16IS7xxManager* SC16IS7xxManager::manager = nullptr;

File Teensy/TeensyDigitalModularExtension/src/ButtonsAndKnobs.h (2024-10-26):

class Potentiometer
{
    public:
        Potentiometer(const uint16_t& digitalPin, const uint16_t& analogPin) 
        { 
            pinMode(digitalPin, OUTPUT); 
            pinMode(analogPin, INPUT_DISABLE); 
            this->digitalPin = digitalPin; 
            this->analogPin = analogPin; 
        }

        float read()
        {
            digitalWrite(digitalPin, HIGH);
            uint sample = 0;
            for (int i = 0; i < oversampling; i++)
            {
                sample += analogRead(analogPin);
            }
            digitalWrite(digitalPin, LOW);

            previousEMASample = previousEMASample + alpha * ((sample / (float)oversampling) - previousEMASample);
            
            if(abs(previousSample - int(previousEMASample)) > 1)
                previousSample = previousEMASample;
                  
            return previousSample / 1023.0f;
        }

    private:
        uint16_t digitalPin, analogPin;
        float alpha = 0.05, previousEMASample = 0;
        int previousSample = 0;
        const uint16_t oversampling = 1;
};

class Button
{
  public:
    Button(const uint16_t& digitalPin, bool inverted){ pinMode(digitalPin, INPUT_PULLUP); this->buttonPin = digitalPin; this->inverted = inverted;}
    Button(const uint16_t& digitalPin, bool inverted, uint8_t mode) { pinMode(digitalPin, mode); this->buttonPin = digitalPin; this->inverted = inverted; }

    bool read()
    {
      bool reading = digitalRead(buttonPin);

      if(debounceTime > debounceDelay)
      {
        lastState = reading;
        debounceTime = 0;
      }
      
      if(reading != lastState)
      {
        debounceTime += millis() - lastTime;
      }
      else
      {
        debounceTime = 0;
      }
      lastTime = millis();
      return inverted ? !lastState : lastState;
    };

  private:
    uint16_t buttonPin;
    bool inverted = false;
  
    bool lastState = false;
    uint32_t debounceTime = 0;
    uint32_t lastTime = 0;

    const uint16_t debounceDelay = 10;
};

class SignalInput
{
    public: 
        SignalInput(const uint16_t& analogPin) { this->analogPin = analogPin; }

        float read()
        {
            uint sample = 0;
            for (int i = 0; i < oversampling; i++)
            {
                sample += analogRead(analogPin);
            }
            return sample / (float)oversampling;
        }

    private:
        uint16_t analogPin;
        const uint16_t oversampling = 256;
};

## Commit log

2024-05-06 Added library with implementation for teensy audio
2024-06-02 Added power specification
2024-06-07 Added ADSR PCB
    [ADSRModule.kicad_pcb, ADSRModule.kicad_sch, Cut.dxf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]
2024-06-09 Fixed component names on schematic
    [ADSRModule.kicad_pcb, ADSRModule.kicad_sch]
2024-06-16 Added VCAModule PCB
    [Cut.dxf, VCAModule.kicad_pcb, VCAModule.kicad_sch]
2024-06-24 Added USB_IO module PCB
    [ADSRModule.kicad_pcb, ADSRModule.kicad_sch, Cut.dxf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]
2024-07-01 Replaced Schematic Lines with references
    [ADSRModule.kicad_pcb, ADSRModule.kicad_sch, Input.kicad_sch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]
2024-07-10 Added Wavetable VCO
    [Cut.dxf, WavetableVCOModule.kicad_pcb, WavetableVCOModule.kicad_sch]
2024-07-11 Added Power connector and bracket
    [Input.kicad_sch, OLED Bracket.stl, Output.kicad_sch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]
2024-07-21 Added Panel PCBs
    [ADSRModule.kicad_pcb, ADSR_Cut.dxf, ADSR_Module.kicad_pcb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]
2024-07-25 Generated Gerbers
    [ADSR_Module.kicad_pcb, ADSR_Panel.kicad_pcb, USB_IO_Module.kicad_pcb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]
2024-08-09 Improved ADSR module
    [ADSR_Module.kicad_pcb]
2024-09-22 Made NPTH holes 0.5mm bigger; adjusted diode pads for better solderability
    [ADSR_Module.kicad_pcb, ADSR_Panel.kicad_pcb, Input.kicad_pcb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]
2024-10-26 Added USB-C Power Supply
    [Output.kicad_sch, USB-C_3A_PSU.kicad_pcb, USB-C_3A_PSU.kicad_sch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]
